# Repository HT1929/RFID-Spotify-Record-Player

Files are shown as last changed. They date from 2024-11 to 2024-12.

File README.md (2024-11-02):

# RFID-Spotify-Record-Player
Instead of vinyl records, RFID chips embedded in custom-made mini-records will trigger specific Spotify songs via a Raspberry Pi. The system mimics the action of placing a record on a turntable, offering both a visual spinning effect and the vast music library of Spotify.

# Project Overview
The RFID Spotify Record Player allows users to:
- Play, pause, skip and control volume for Spotify tracks.
- Select songs or playlists through a physical interface using the RFID sensor.
- Output audio through a built-in speaker system.
- Watch a disk spin as if it were playing a vinyl record, adding to the aesthetic of a traditional record player.

# Features
**User Interface:** Physical controls for playback and navigation.

**Controller:** Manages user inputs and communicates with Spotify.

**Network Module:** Connects to Wi-Fi to access the Spotify API.

**Spinning Disk:** A motorized disk spins to mimic the look of a record on a turntable.

**Spotify Integration:** Streams music directly from Spotify using the Spotify API.

**Audio Output:** Plays audio through connected speakers.

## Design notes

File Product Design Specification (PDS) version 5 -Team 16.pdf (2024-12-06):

### Practicum Product Design Specification (PDS)

Team 16

RFID Spotify Record Player

Date: 12/5/2024

Version 5

Lam Vo, Hiep Thieu
Natalie Kashoro, Daisy Perez-Ruiz

Executive Summary with Concept of Operations:
The RFID Spotify Record Player bridges the nostalgic experience of using a record player with the convenience of digital music streaming. Instead of vinyl records, RFID chips embedded in custom made mini-records will trigger specific Spotify songs via a Raspberry Pi. The system mimics the action of placing a record on a turntable, offering both a visual spinning effect and the vast music library of Spotify.

How it works:

- The user places an RFID-embedded "record" on the player.
- The RFID reader detects the tag.
- The Raspberry Pi processes this input, sends a command to Spotify to play a specific song, and simultaneously activates a DC motor to spin the mini-record for a visual effect.

Users:
Music enthusiasts who enjoy a blend of old-school vinyl aesthetics with modern music streaming.

Market Analysis:

- Target Users: Retro tech enthusiasts and individuals who appreciate unique user interfaces for their music experience.
- Competition: Competitors may include similar DIY projects combining Raspberry Pi, Spotify, and RFID. However, most of these don’t focus on the retro look and feel of a record player combined with Spotify.
- Unique Selling Point (USP): The product stands out for offering a visually satisfying, tactile experience with the practical convenience of Spotify's music library.
- Price Estimation: The expected price for parts and assembly would be around $100-$150, keeping it affordable compared to high-end custom audio systems, but competitive for a niche product.

Requirements:

- Must accurately read RFID tags within 1-2 seconds.
- Must connect to Spotify via a Wi-Fi or Ethernet connection.
- Must trigger a corresponding song and/or playlist based on the RFID chip.
- Must offer a smooth, lag-free music playing experience.
- Must not overheat during extended use.
- Should include a visual spinning effect of the mini-record.
- Should include an LCD displaying the song playing.
- Should be portable and powered (ex. standard AC adapter / rechargeable battery)
- Should have action buttons/RFID tags to control pause, play, skip, and reverse.
- Should be easy to set up with minimal configuration needed by the user.
- Should have a "shuffle" mode for random song playback.
- Should include a time display or countdown of the song playing.
- Should have adjustable volume control via buttons or a rotary knob.
- Should include support for multiple user profiles, allowing different users to have personalized playlists or settings.
- Should have a low-power mode to conserve battery when not in active use.
- Should offer a sleep timer that gradually lowers volume and shuts off after a set time.
- Should have a “favorite” button that lets users save the current track to a playlist.
- Should provide an adjustable motor speed to create different visual effects for the spinning disc.
- Should provide a visual notification for low signal strength if the Wi-Fi connection is weak.
- Should include a mute button to instantly stop sound output without turning off the device.
- Should provide an option to adjust the brightness of the LCD display.
- Should offer a feature to create playlists from RFID tags based on user preferences.

System Architecture:

- Level 0 Block Diagram:

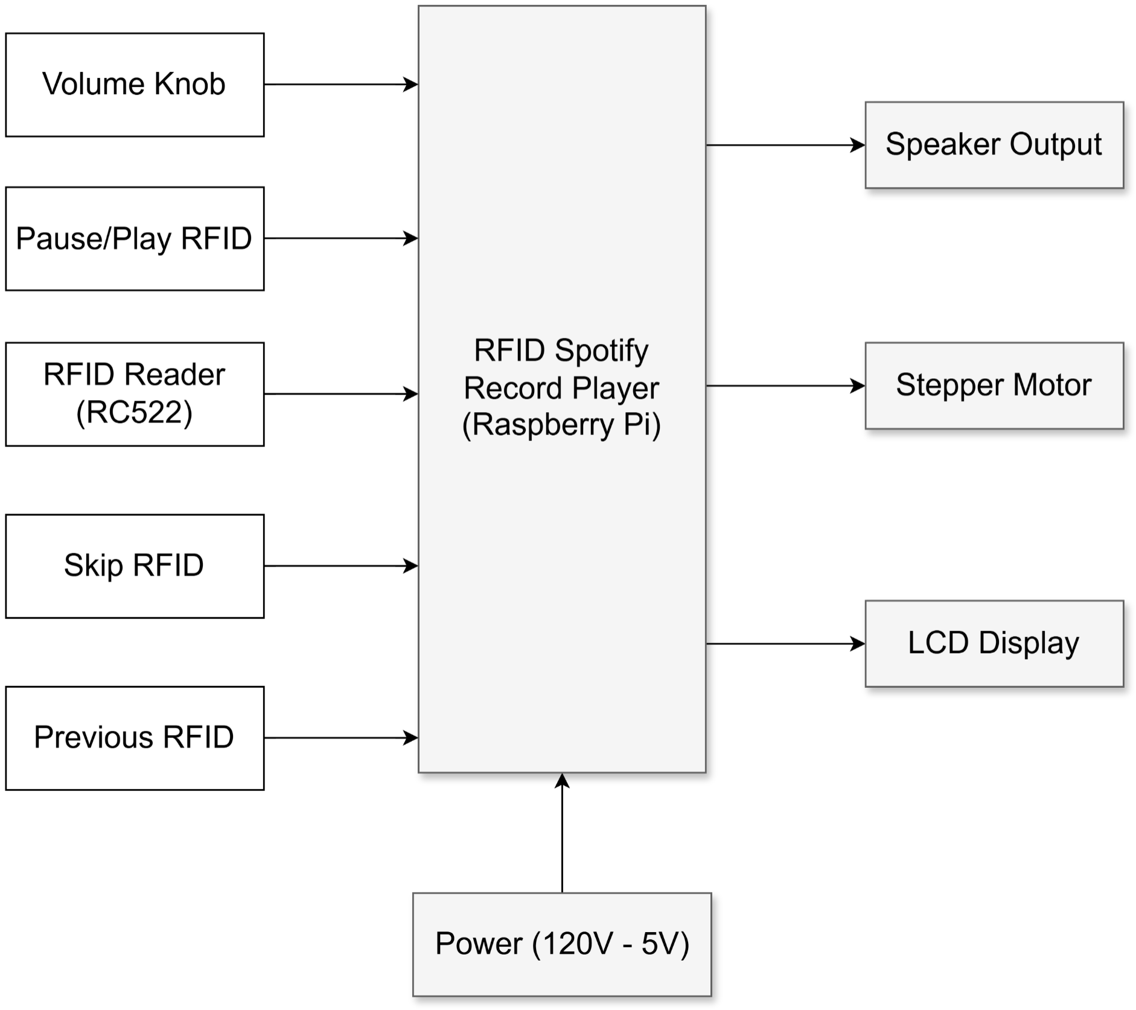
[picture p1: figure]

Module | RFID Spotify Record Player (Raspberry Pi)

Input | Volume knob Pause/play button RFID reader(RC522) Skip button Previous button Power(wall outlet 120V to input 5V)
Output | Speaker output Stepper motor LCD display
Functionality | Receive signal from RFID tag and process it to link with Spotify playlist and output the playlist.
- Level 1 Block Diagram:

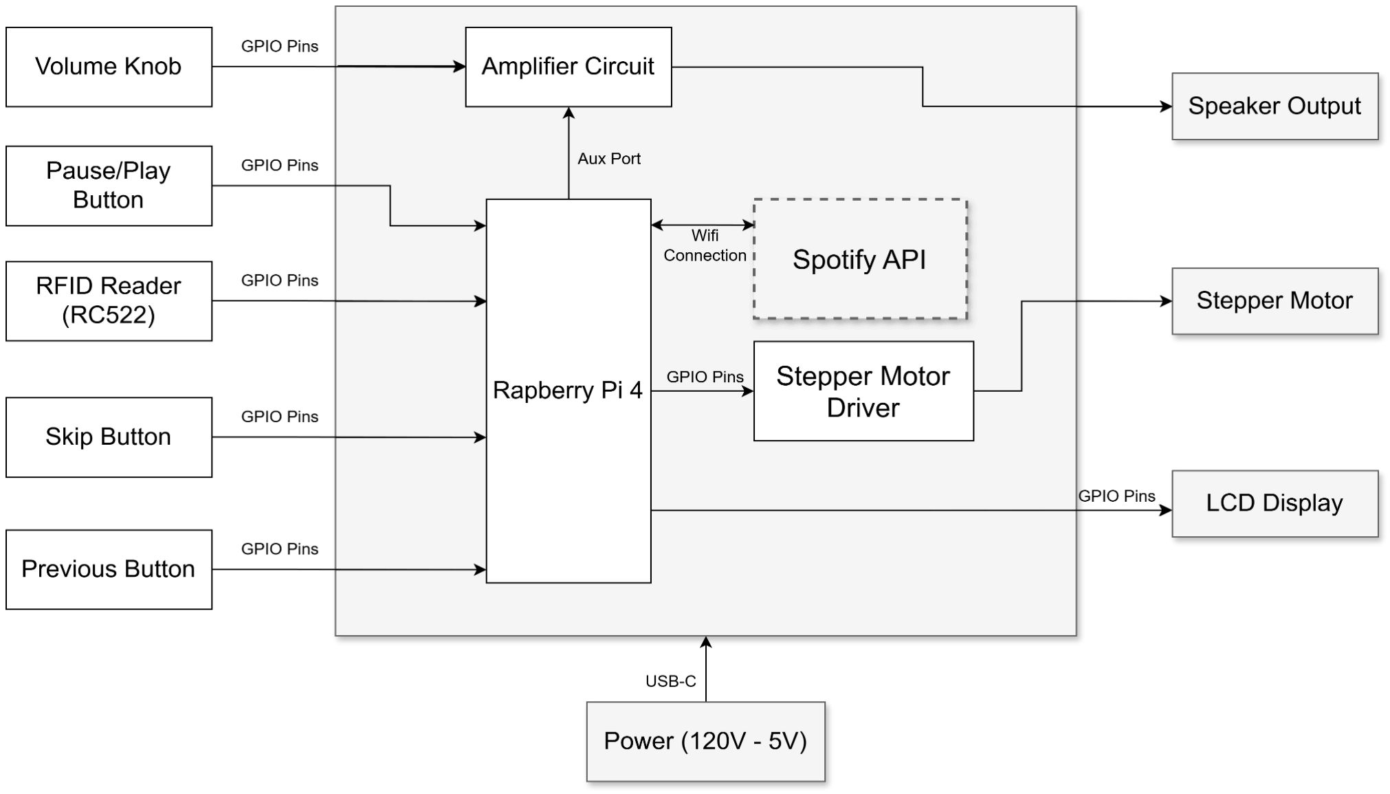
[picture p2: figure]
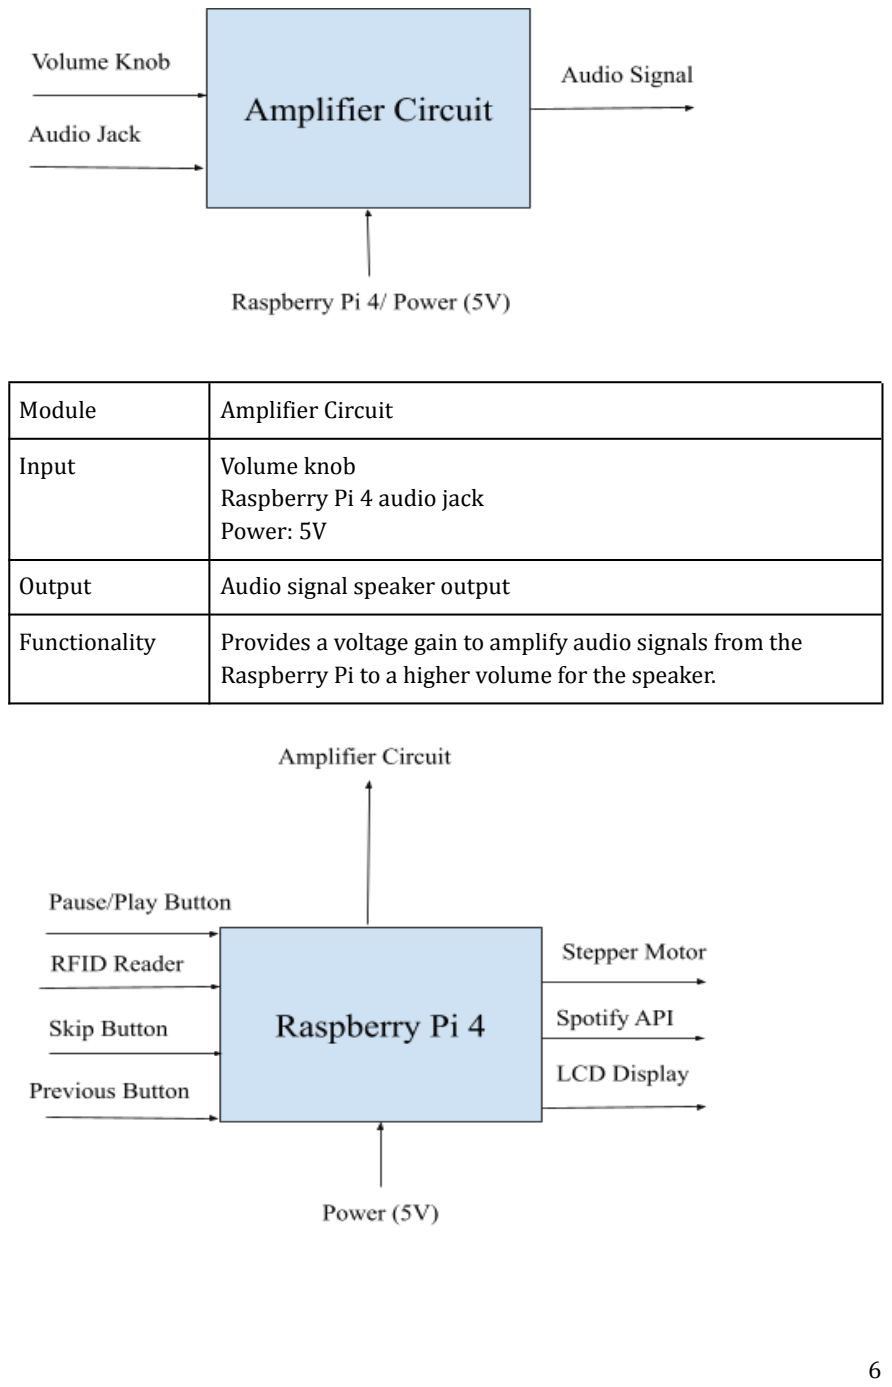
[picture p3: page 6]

Module | Amplifier Circuit
Input | Volume knob Raspberry Pi 4 audio jack Power: 5V
Output | Audio signal speaker output
Functionality | Provides a voltage gain to amplify audio signals from the Raspberry Pi to a higher volume for the speaker.

Module | Raspberry Pi 4
Input | Pause/play button RFID reader Skip button Previous button Power: 5V
Output | Stepper motor Spotify API LCD display
Functionality | Reads RFID tags, communicates with Spotify API to play corresponding songs, controls playback functions, and sends data to the LCD Display and stepper motor.

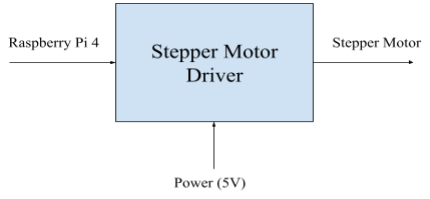
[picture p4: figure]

Module | Stepper Motor Driver
Input | Raspberry Pi 4 Power: 5V
Output | Stepper motor
Functionality | Controls the rate of rotation of the stepper motor to spin the mini-record player, simulating a traditional record player effect.

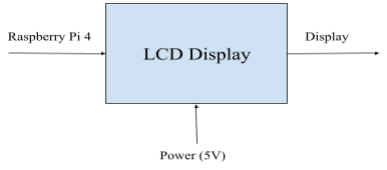
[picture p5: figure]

Module | LCD Display
Input | Raspberry Pi 4 Power: 5V
Output | LCD display
Functionality | Display the song title, playback control performed, or errors in playing a song.

Design Specification:

- Sensor: RFID reader (RC522 module).
- Processor: Raspberry Pi 4 (handles RFID reading, Spotify API interaction, and motor control).
- Actuator: Small DC motor to spin the mini-record.
- Display: LCD screen to show song details, playback controls, and status notifications.
- Power Supply: 5V, 2.5A power supply for Raspberry Pi; 5V motor driver (same power connection).
- Software: Python scripts for RFID reading and interfacing with Spotify's API; Motor control, and LCD Management via GPIO.
- Mechanical Design: Mini-record platter driven by a DC motor, audio jack-connected speaker, and integrated LCD for feedback.
- Firmware/Development Environment: Raspberry Pi OS, Python, Spotify API, and necessary libraries for LCD control.

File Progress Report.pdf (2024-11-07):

Team 16
Professor Greenberg
11/7/2024

Status Report: RFID Spotify Record Player

Project Overview:
The RFID Spotify Record Player aims to combine the nostalgic experience of a traditional record player with the convenience of digital streaming. Utilizing RFID chips embedded within custom miniature records, the device initiates playback of specific songs on Spotify through a Raspberry Pi. A DC motor enhances the experience by creating a rotating visual effect, mimicking the traditional record-playing ambiance.

Current Status:
The project is progressing on schedule, and a working prototype without an LCD screen has been completed. Major achievements include:
- Concept and Design Completed: The overall design, including the Level 0 and Level 1 block diagrams, has been finalized. These diagrams map out the system’s major components and their interactions, providing a clear visual foundation for implementation.
- Component Selection: The Raspberry Pi, RC522 RFID reader module, and DC motor have been selected as primary hardware components. Initial tests indicate compatibility with the project’s requirements.
- Software Integration Completed: The RFID reader has been successfully integrated with the Spotify API, enabling song playback based on the RFID tag input.

Project Pictures:

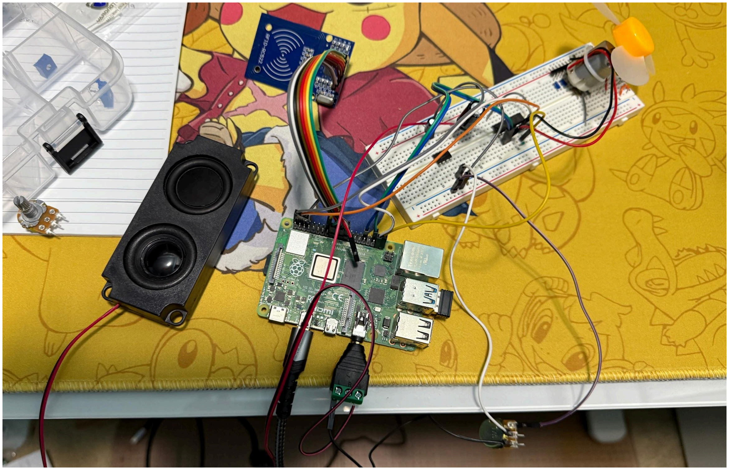
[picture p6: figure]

Video link:
https://drive.google.com/file/d/1K7AMLiBzfWugOn-8HSeIKXvq5kMZzPSX/view?usp=drive_l ink (https://drive.google.com/file/d/1K7AMLiBzfWugOn-8HSeIKXvq5kMZzPSX/view?usp=drive_link)

Next Steps:
1. Acquire and integrate an LCD screen for displaying the song title and playback status.
2. Design and test an amplifier circuit to enhance audio quality and volume.
3. 3D printing custom components for the player casing and mini-record holders will complete the visual design.
4. Conduct full-system testing to ensure reliability, smooth operation, and user experience.

Challenges:
- Speaker Amplification: The audio output from the Raspberry Pi lacks sufficient power to drive the speaker at a higher volume, requiring an amplifier solution.
- 3D Printing Fit and Quality: Ensuring that custom 3D-printed parts fit well with the prototype and align with the visual design.

Conclusion:
While the project is progressing well, with essential components and preliminary software development already established, it is important to continue staying on schedule due to the time limitations. We will be facing some challenges within the coming weeks, but will remain focused on integration and testing to advance toward a fully functional prototype.

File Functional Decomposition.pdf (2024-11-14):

Team 16
Professor Greenberg
ECE 424
11/14/2024

Functional Decomposition

Level 0 Block Diagram:

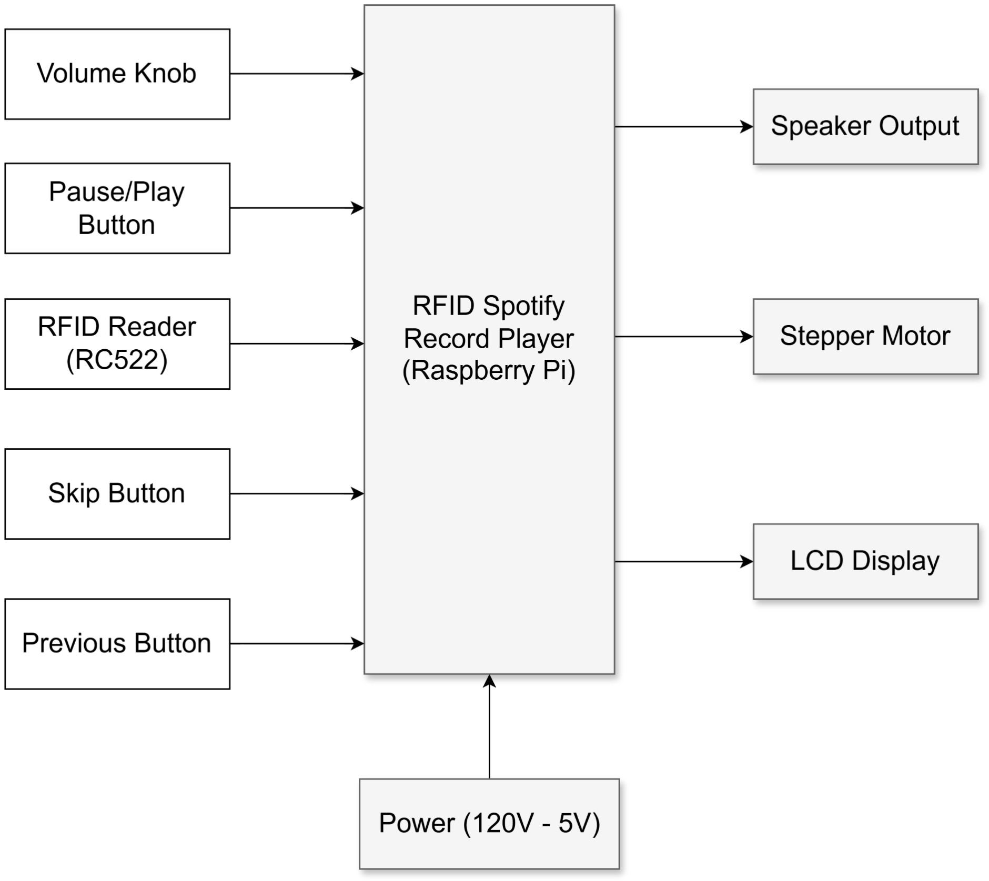
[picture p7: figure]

Module | RFID Spotify Record Player (Raspberry Pi)
Input | Volume knob Pause/play button RFID reader(RC522) Skip button Previous button Power(wall outlet 120V to input 5V)
Output | Speaker output Stepper motor LCD display
Functionality | Receive signal from RFID tag and process it to link with Spotify playlist and output the playlist.

Level 1 Block Diagram:

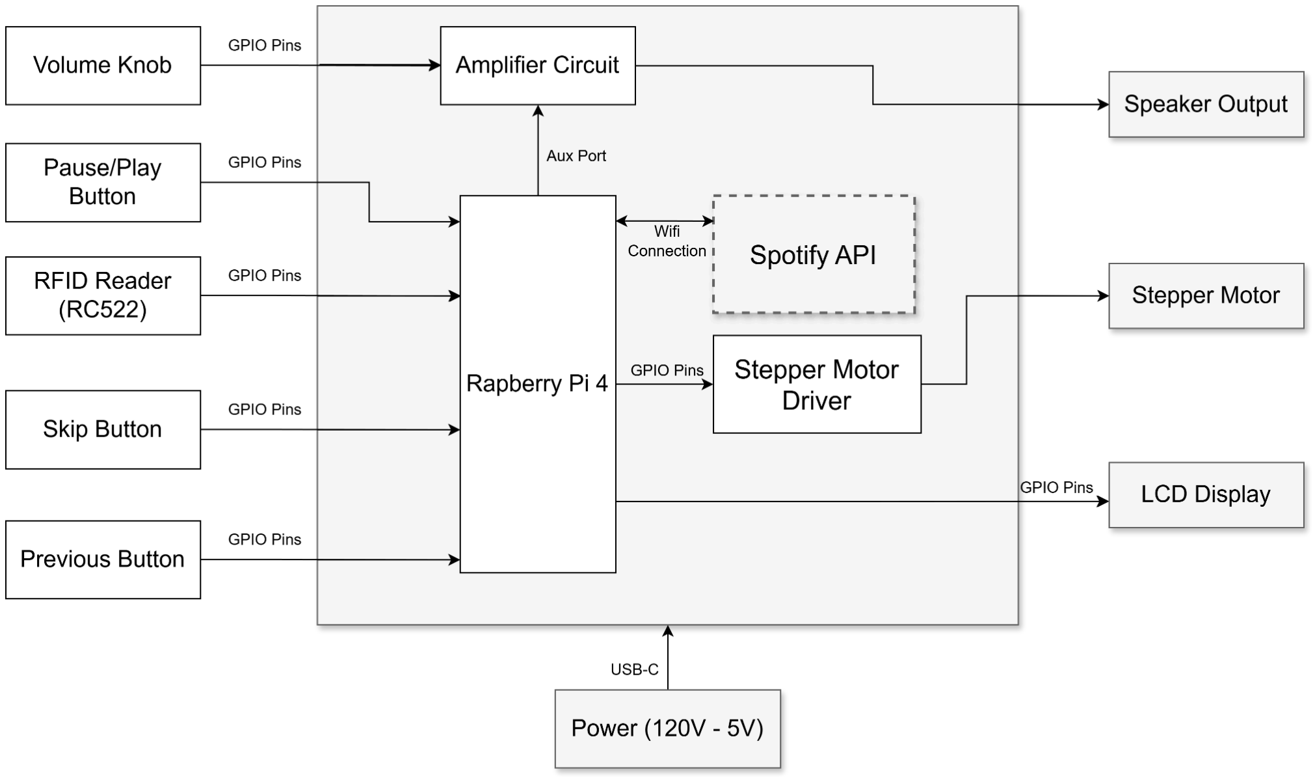
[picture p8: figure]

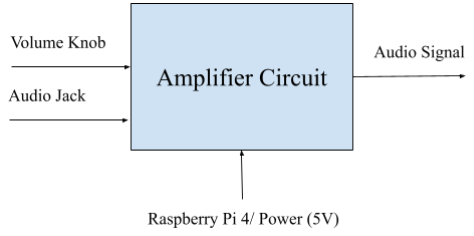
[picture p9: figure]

Module | Amplifier Circuit
Input | Volume knob Raspberry Pi 4 audio jack Power: 5V
Output | Audio signal speaker output
Functionality | Provides a voltage gain to amplify audio signals from the Raspberry Pi to a higher volume for the speaker.

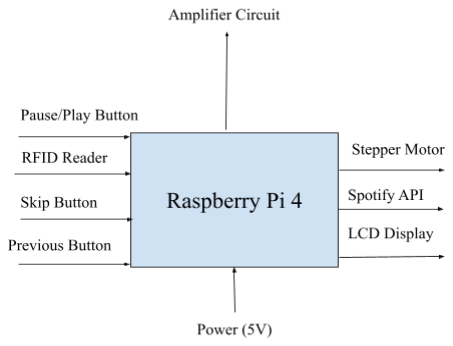
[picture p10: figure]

Module | Raspberry Pi
Input | Pause/play button RFID reader Skip button Previous button Power: 5V
Output | Stepper motor Spotify API LCD display
Functionality | Reads RFID tags, communicates with Spotify API to play corresponding songs, controls playback functions, and sends data to the LCD Display and stepper motor.

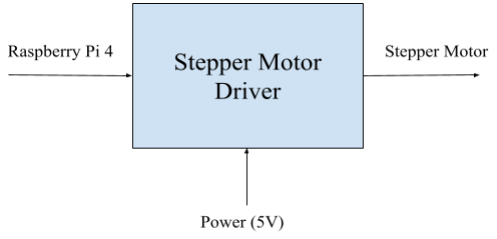
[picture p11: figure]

Module | Stepper Motor Driver
Input | Raspberry Pi 4 Power: 5V
Output | Stepper motor
Functionality | Controls the rate of rotation of the stepper motor to spin the mini-record player, simulating a traditional record player effect.

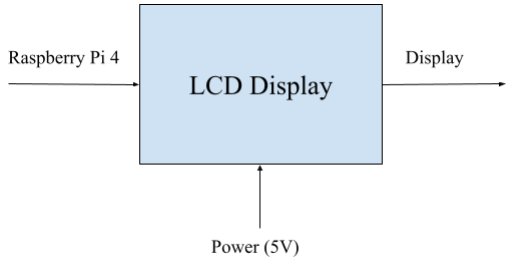
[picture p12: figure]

Module | LCD Display
Input | Raspberry Pi 4 Power: 5V
Output | LCD display
Functionality | Display the song title, playback control performed, or errors in playing a song.

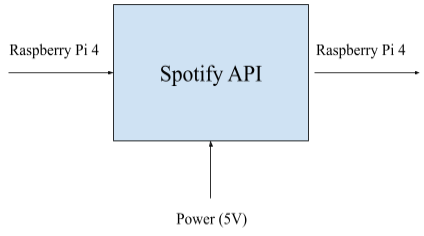
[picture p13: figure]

Module | Spotify API
Input | Pause/play command RFID reader Skip command Previous command Power: 5V
Output | Music playback
Functionality | Connects with Spotify to stream the selected song based on RFID input and provides playback control.

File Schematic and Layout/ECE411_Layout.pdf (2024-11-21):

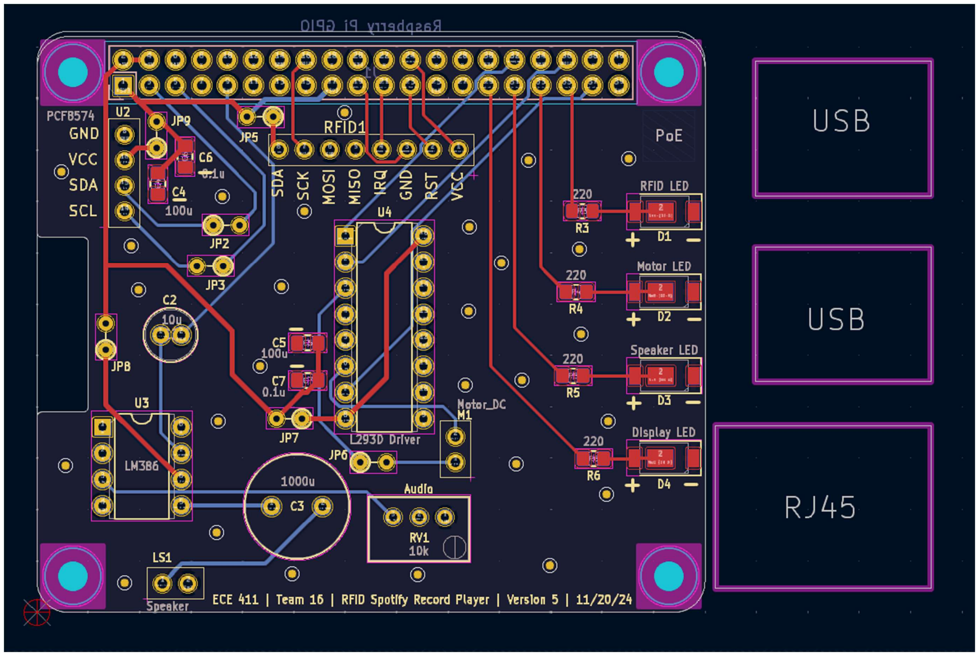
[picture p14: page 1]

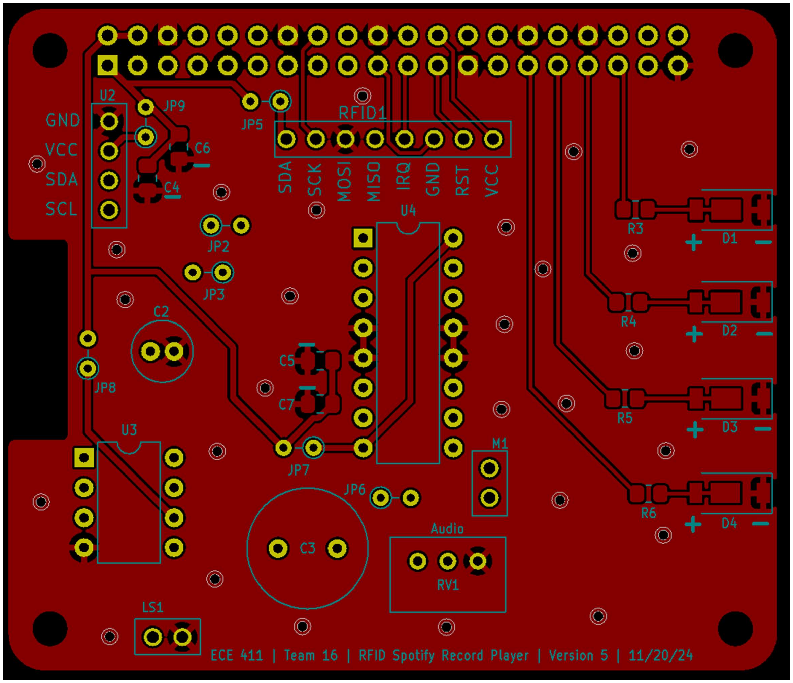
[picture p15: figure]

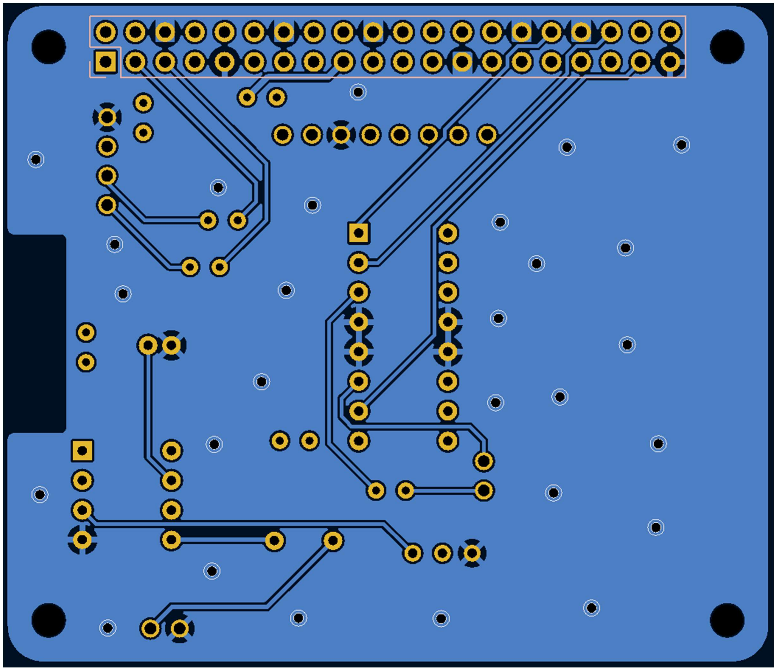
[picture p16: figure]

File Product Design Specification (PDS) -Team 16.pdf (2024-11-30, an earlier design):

### Practicum Product Design Specification (PDS)

Team 16

RFID Spotify Record Player

Date: 11/19/2024

Version 3

Lam Vo, Hiep Thieu
Natalie Kashoro, Daisy Perez-Ruiz

Executive Summary with Concept of Operations:
The RFID Spotify Record Player bridges the nostalgic experience of using a record player with the convenience of digital music streaming. Instead of vinyl records, RFID chips embedded in custom made mini-records will trigger specific Spotify songs via a Raspberry Pi. The system mimics the action of placing a record on a turntable, offering both a visual spinning effect and the vast music library of Spotify.

How it works:

- The user places an RFID-embedded "record" on the player.
- The RFID reader detects the tag.
- The Raspberry Pi processes this input, sends a command to Spotify to play a specific song, and simultaneously activates a DC motor to spin the mini-record for a visual effect.

Users:
Music enthusiasts who enjoy a blend of old-school vinyl aesthetics with modern music streaming.

Market Analysis:

- Target Users: Retro tech enthusiasts and individuals who appreciate unique user interfaces for their music experience.
- Competition: Competitors may include similar DIY projects combining Raspberry Pi, Spotify, and RFID. However, most of these don’t focus on the retro look and feel of a record player combined with Spotify.
- Unique Selling Point (USP): The product stands out for offering a visually satisfying, tactile experience with the practical convenience of Spotify's music library.
- Price Estimation: The expected price for parts and assembly would be around $100-$150, keeping it affordable compared to high-end custom audio systems, but competitive for a niche product.

Requirements:

- Must accurately read RFID tags within 1-2 seconds.
- Must connect to Spotify via a Wi-Fi or Ethernet connection.
- Must trigger a corresponding song and/or playlist based on the RFID chip.
- Must offer a smooth, lag-free music playing experience.
- Must not overheat during extended use.
- Should include a visual spinning effect of the mini-record.
- Should include an LCD displaying the song playing.
- Should be portable and powered (ex. standard AC adapter / rechargeable battery)
- Should have action buttons/RFID tags to control pause, play, skip, and reverse.
- Should be easy to set up with minimal configuration needed by the user.
- Should have a "shuffle" mode for random song playback.
- Should include a time display or countdown of the song playing.
- Should have adjustable volume control via buttons or a rotary knob.
- Should include support for multiple user profiles, allowing different users to have personalized playlists or settings.
- Should have a low-power mode to conserve battery when not in active use.
- Should offer a sleep timer that gradually lowers volume and shuts off after a set time.
- Should have a “favorite” button that lets users save the current track to a playlist.
- Should provide an adjustable motor speed to create different visual effects for the spinning disc.
- Should provide a visual notification for low signal strength if the Wi-Fi connection is weak.
- Should include a mute button to instantly stop sound output without turning off the device.
- Should provide an option to adjust the brightness of the LCD display.
- Should offer a feature to create playlists from RFID tags based on user preferences.

System Architecture:

- Level 0 Block Diagram:

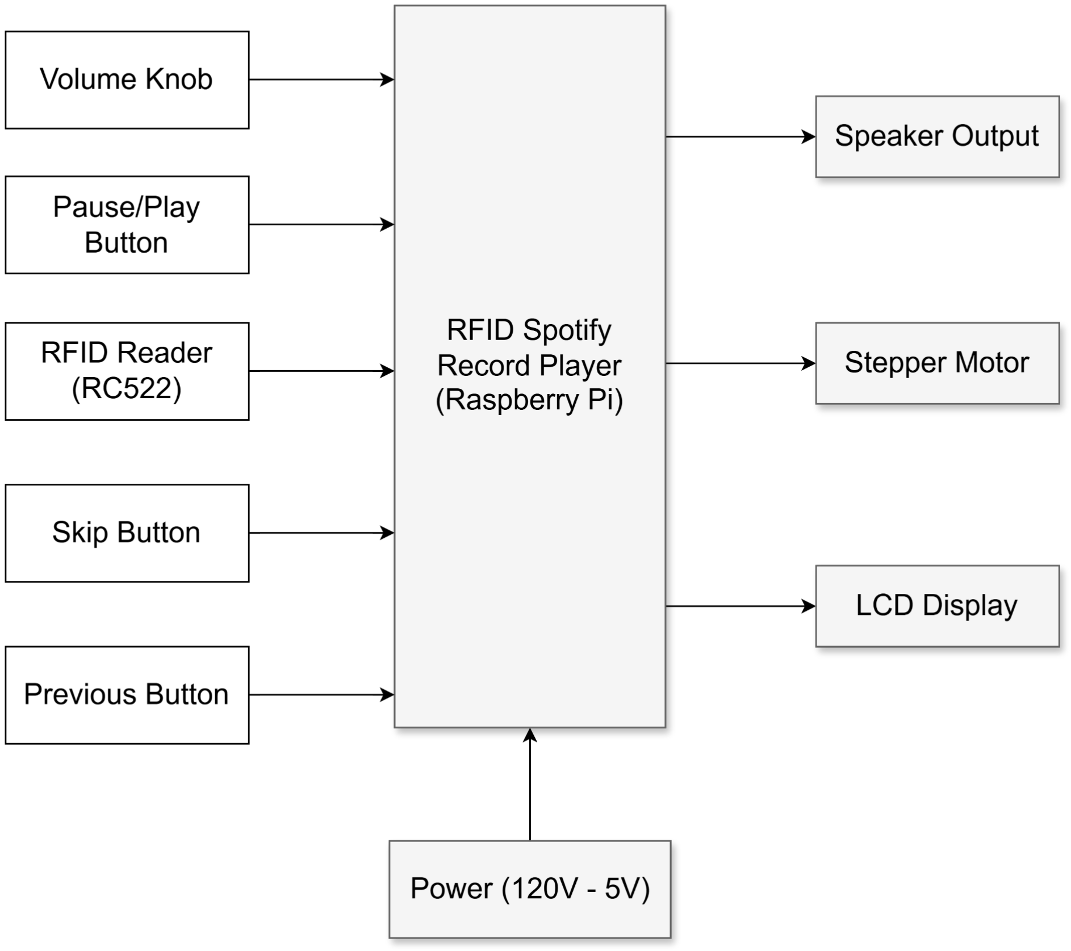
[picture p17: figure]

Module | RFID Spotify Record Player (Raspberry Pi)
Input | Volume knob Pause/play button RFID reader(RC522) Skip button Previous button Power(wall outlet 120V to input 5V)
Output | Speaker output Stepper motor LCD display
Functionality | Receive signal from RFID tag and process it to link with Spotify playlist and output the playlist.
- Level 1 Block Diagram:

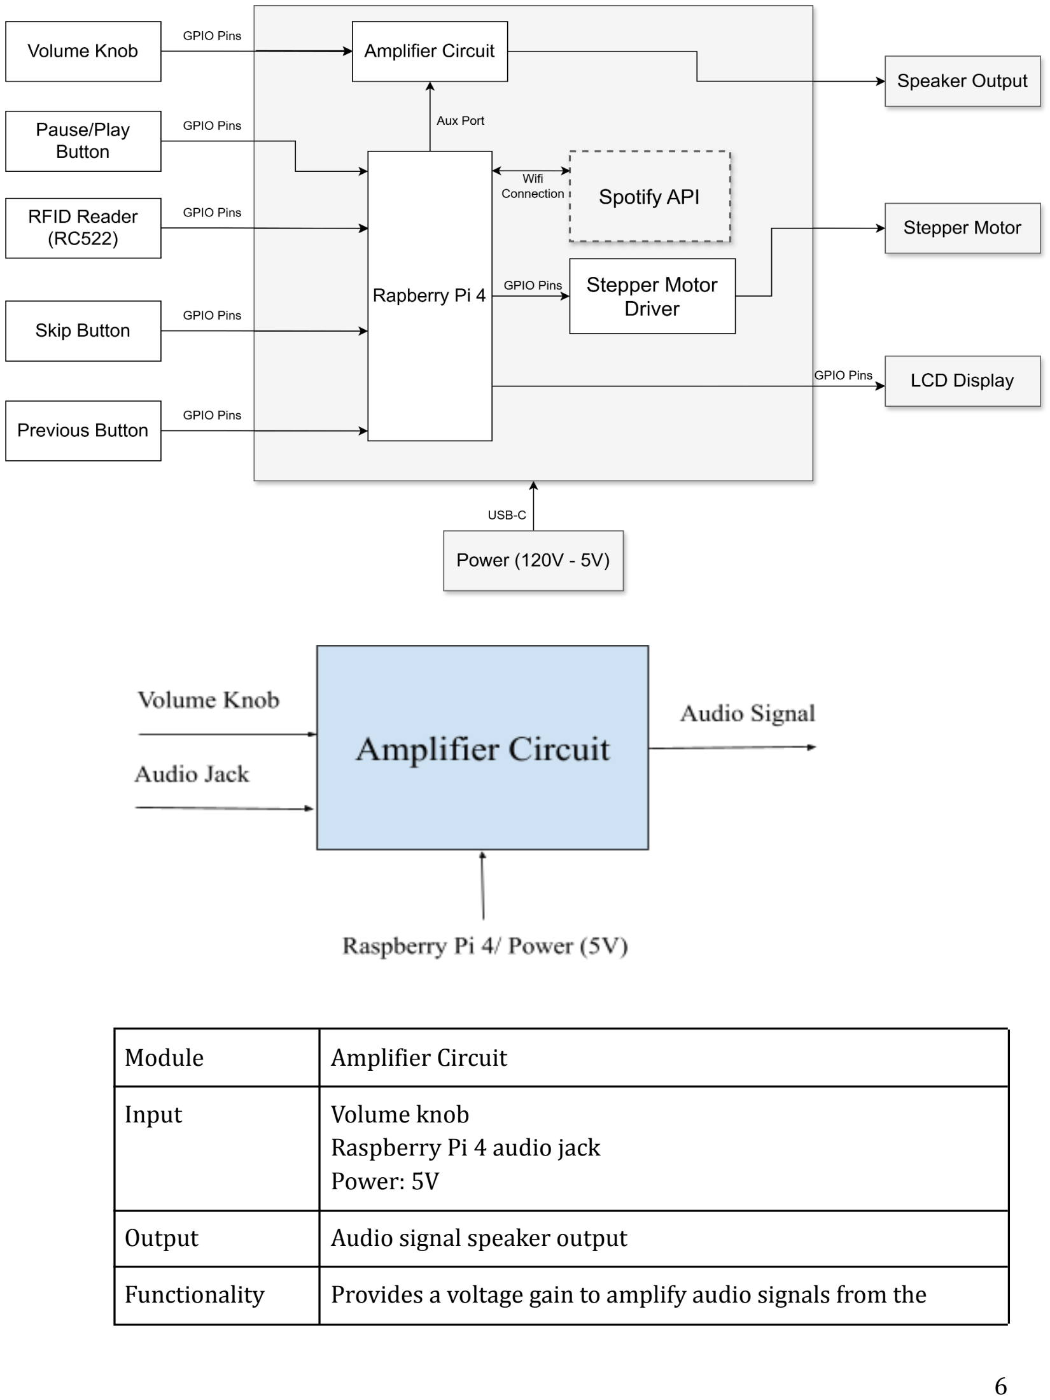
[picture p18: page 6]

Module | Amplifier Circuit
Input | Volume knob Raspberry Pi 4 audio jack Power: 5V
Output | Audio signal speaker output
Functionality | Provides a voltage gain to amplify audio signals from the

Raspberry Pi to a higher volume for the speaker.

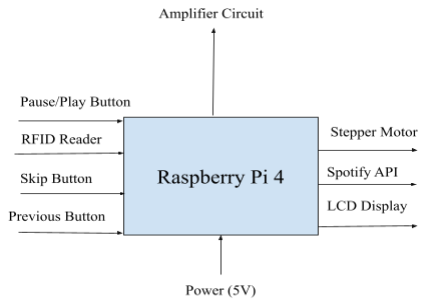
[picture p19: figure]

Module | Raspberry Pi 4
Input | Pause/play button RFID reader Skip button Previous button Power: 5V
Output | Stepper motor Spotify API LCD display
Functionality | Reads RFID tags, communicates with Spotify API to play corresponding songs, controls playback functions, and sends data to the LCD Display and stepper motor.

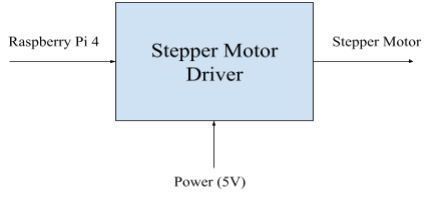
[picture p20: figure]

Module | Stepper Motor Driver
Input | Raspberry Pi 4 Power: 5V
Output | Stepper motor
Functionality | Controls the rate of rotation of the stepper motor to spin the mini-record player, simulating a traditional record player effect.

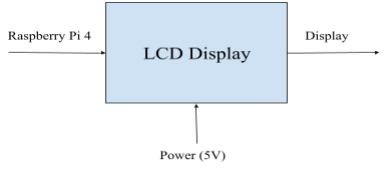
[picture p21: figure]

Module | LCD Display
Input | Raspberry Pi 4 Power: 5V
Output | LCD display
Functionality | Display the song title, playback control performed, or errors in playing a song.

Design Specification:

- Sensor: RFID reader (RC522 module).
- Processor: Raspberry Pi 4 (handles RFID reading, Spotify API interaction, and motor control).
- Actuator: Small DC motor to spin the mini-record.
- Power Supply: 5V, 2.5A power supply for Raspberry Pi; 5V motor driver (same power connection).
- Software: Python scripts for RFID reading and interfacing with Spotify's API; Motor control via GPIO.
- Mechanical Design: Mini-record platter driven by a DC motor and audio jack connected speaker.
- Firmware/Development Environment: Raspberry Pi OS, Python, Spotify API.

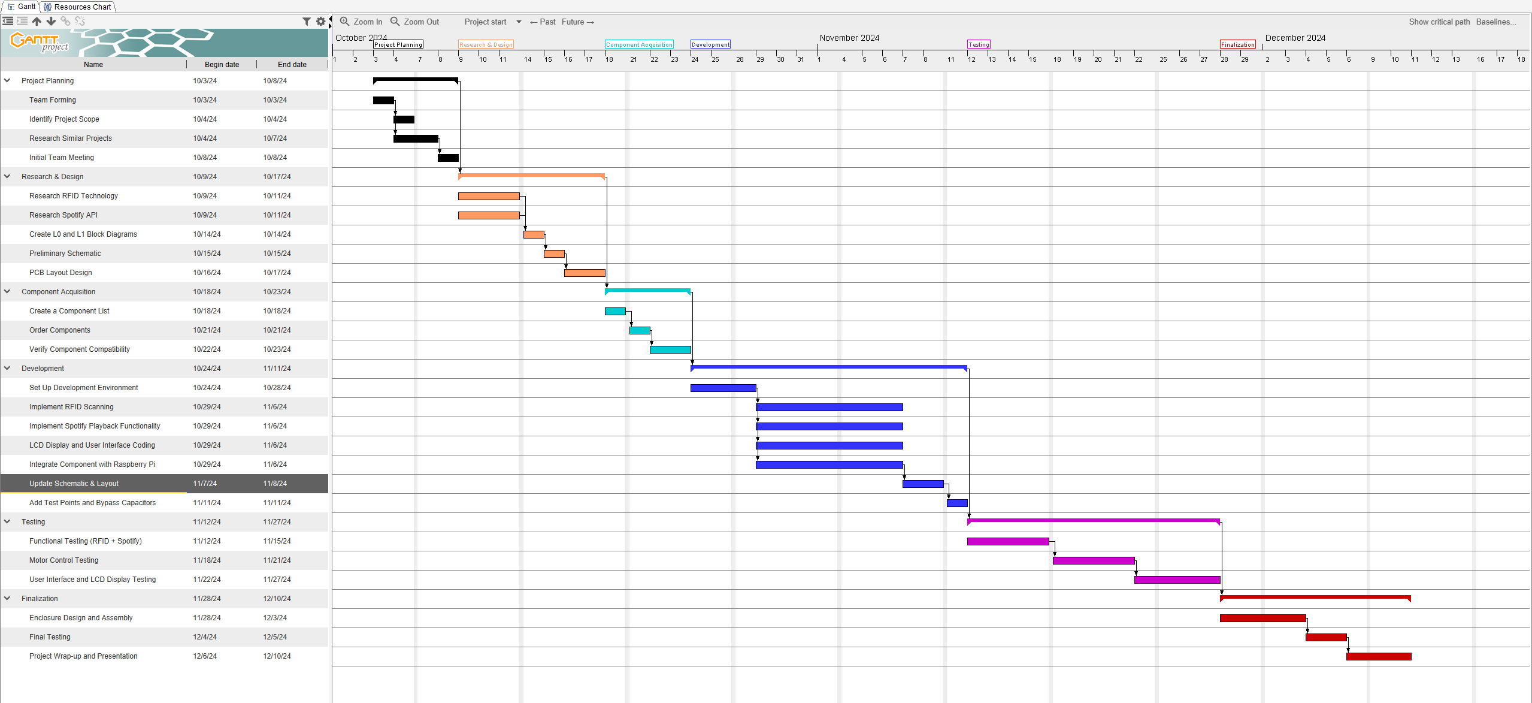
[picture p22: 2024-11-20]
Gantt_Chart/ECE 411 Gant Chart Updated.PNG

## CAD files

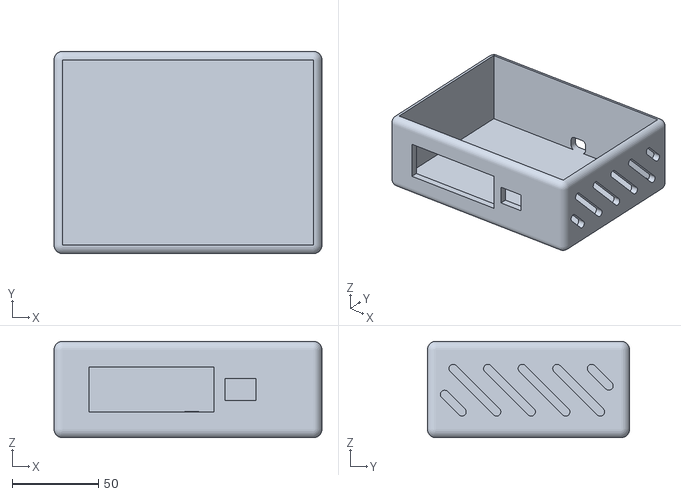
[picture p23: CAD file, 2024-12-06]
3D Design Model/box bottom v5.stl
155.0 x 117.0 x 55.8

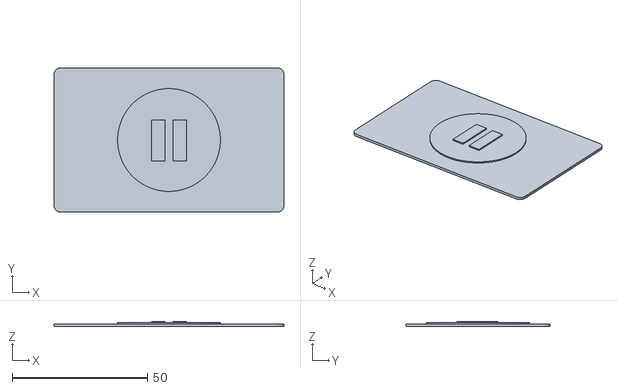
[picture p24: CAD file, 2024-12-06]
3D Design Model/pause v3.stl
85.0 x 53.3 x 2.00

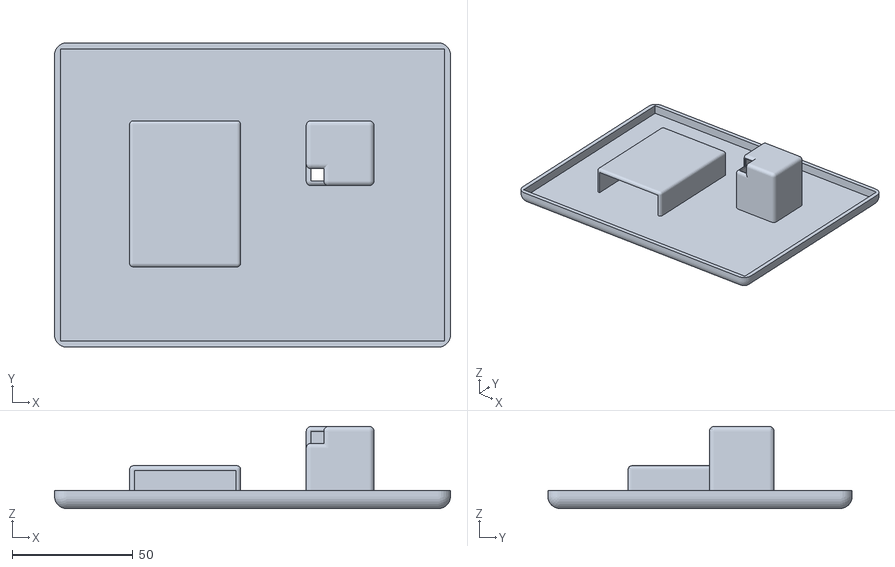
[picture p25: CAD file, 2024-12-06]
3D Design Model/bot top v4.stl
164.0 x 126.0 x 34.0

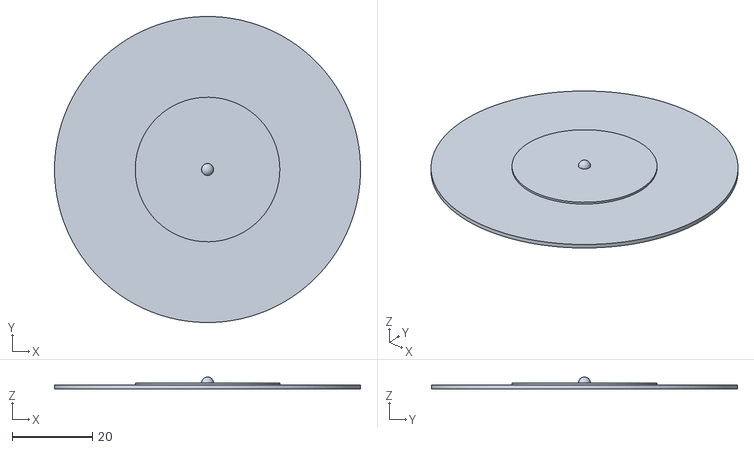
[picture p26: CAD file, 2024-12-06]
3D Design Model/disc v2.stl
76.2 x 76.2 x 3.00

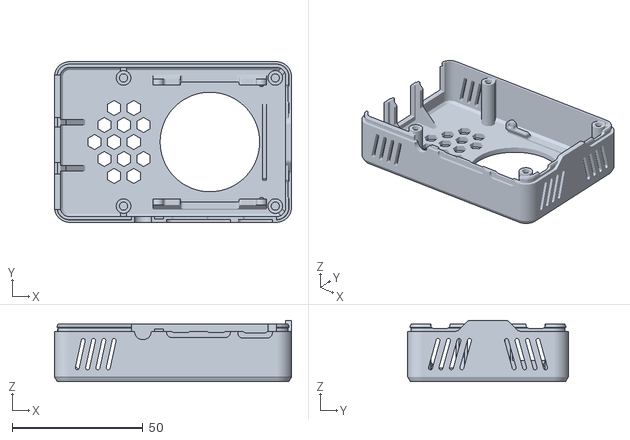
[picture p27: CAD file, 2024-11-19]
3D Design Model/3d_Top_rev1.stl
90.6 x 61.4 x 23.4

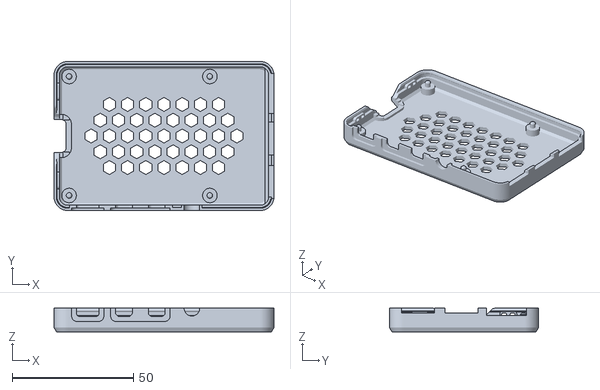
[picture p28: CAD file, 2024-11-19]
3D Design Model/3d_Bottom_rev1.stl
90.6 x 61.4 x 9.70

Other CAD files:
3D Design Model/play v2.stl
3D Design Model/skip v3.stl

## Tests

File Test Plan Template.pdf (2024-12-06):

Hiep Thieu, Lam Vo, Daisy Perez, Natalie Kashoro | 12/5/2024 | ECE 411

Test Author: Group 16
Test Case Name: | Music playing Path Test #1 | Test ID #: | MPP-01
Description: | Set up the RFID reader to identify tags linked to specific Spotify playlists and play the associated music through the connected speaker. | Type: | white box black box ________

Tester Information
| Name of Tester: | Hiep Thieu and Daisy Perez | Date: | Dec 4 2024
| HW/SW Version: | 1.0 | Time: | 2PM
| Setup: | Connect the Raspberry Pi to the audio system and an RFID scanner. Do not connect the jumpers for other subsystems.
S T E P | Action | Expected Result | P A S S | F A I L | N / A | Comments
1 | Have mobile device detect raspberry Pi | Spotify connects to raspotify | x | | | Raspotify is the raspberry pi name when searching on Spotify
2 | Begin Program | Volume should be low/muted, the output display screen should show “Scan RFID…” when program runs | x | | | Use a test code instead of the main, full code
3 | Scan song RFID | Spotify should load playlist on phone and begin playing | x
4 | Turn the volume down | Music coming from speaker should be louder | x
5 | Turn the volume up | Music coming from speaker should be quieter | x
6 | Scan music control RFIDs | Pause RFID - pause song, Play RFID - play song, skip RFID - skip song | x
7 | Register RFID | Add RFID id to database, display in the output screen completion or error message. | x | | | Should give error messages depending on the error. Common error we looked for was duplicate RFID trying to reregister.
| Overall test result: | | x
2024-12-5 | Page 1 of 3

Test Author: Group 16

Test Case Name: | RFID detection test | Test ID #: | DT-01
Description: | Verify the range in which the RFID tag can be from the sensor and still be read. | Type: | white box black box ________

Tester Information

| Name of Tester: | Natalie Kashoro and Lam Vo | Date: | Dec 3 2024
| HW/SW Version: | 1.0 | Time: | 8AM
| Setup: | Isolate the sensor from any other type of disruptions. We will be testing only perpendicular from the face of the RFID sensor, not diagonally or horizontally.
T E S T | Distance between RFID Scanner and the RFID Tag | Expected Output | P A S S | F A I L | N / A | Comments
1 | 0 cm | Command Prompt Message : “RFID Detected” | x
2 | 1 cm | Command Prompt Message : “RFID Detected” | x
3 | 2 cm | Command Prompt Message : “RFID Detected” | x
4 | 3 cm | Command Prompt Message : “RFID Detected” | x
5 | 4 cm | Command Prompt Message : “RFID Detected” | | x | | Might need to adjust the 3d printed case so the wall is not as thick
6 | 5 cm | Command Prompt Message : “RFID Detected” | | x | | Test again as a black box test to see if the sensor can detect the RFID tag through the box wall.

7 | 6 cm | Command Prompt Message : “RFID Detected” | | x
| Overall test result: | | x | | 4 cm should be an appropriate radius for the sensor because we want to avoid the possibility of scanning multiple RFIDS due to the larger radius

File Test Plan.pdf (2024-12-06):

Hiep Thieu, Lam Vo, Daisy Perez, Natalie Kashoro ECE 411
December 5, 2024

### Test Plan

Unit Test:
Power Supply
1. Check if the Raspberry Pi gets a steady 5V from the power adapter.
2. Verify that the 3.3V GPIO pin powers the RFID reader correctly.
3. Confirm the motor driver and LCD screen are powered from the 5V GPIO pin without overloading.
RFID Reader
4. Test if valid RFID tags embedded in mini-records are detected.
5. Check that unregistered tags are ignored.
6. Verify consistent detection when scanning multiple tags in a row.
Spinning Disk Motor
7. Confirm the motor spins when a control signal is sent from the Raspberry Pi GPIO pin.
8. Test the motor’s speed consistency while running.
9. Ensure the motor stops spinning when playback is paused.
Audio System
10. Verify sound output through the speakers is clear.
11. Test volume control to ensure it adjusts levels up and down as expected.
12. Check for distortion at maximum volume.
Physical Controls
13. Pressing the play button starts playback.
14. Pressing the pause button stops playback.
15. The skip button advances to the next track.
16. Volume buttons change the audio level accurately.
Spotify Integration
17. Verify the Spotify API triggers the correct song/playlist based on the RFID tag.
18. Ensure playback state (is_playing) updates correctly.
19. Check system response to Spotify errors like no internet connection.
LCD Screen
20. Ensure the LCD powers on and displays text correctly.
21. Check if it shows the current track and artist name.
22. Test scrolling for long song or artist names.

Verification Tests:
1. Mini-record triggers playback:
Placing a mini-record with an embedded RFID tag starts playback of the associated Spotify song or playlist.
2. Mini-record stops playback:
Removing the mini-record pauses Spotify playback and stops the spinning disk.
3. Play button starts playback:
Pressing the physical "Play" button resumes Spotify playback.
4. Pause button stops playback:
Pressing the "Pause" button pauses Spotify playback and stops the spinning disk.
5. Skip button advances track:
Pressing the "Skip" button skips to the next track in the playlist.
6. Volume up increases sound level:
Pressing the "Volume Up" button increases the volume through the built-in speakers.
7. Volume down decreases sound level:
Pressing the "Volume Down" button decreases the volume.
8. LCD updates current track:
When playback starts, the LCD displays the current track name and artist.
9. Scrolling for long text:
If the track name or artist exceeds 16 characters, the LCD scrolls the text smoothly.
10. Spinning disk starts with playback:
The motorized disk starts spinning when Spotify playback begins.
11. Spinning disk stops when paused:
The spinning disk halts when playback is paused or stopped.
12. Unregistered RFID tag has no effect:
Scanning an unregistered RFID tag does not start playback, display a track, or spin the disk.
13. Register new RFID tag to a playing song:
While a song is playing, register a new RFID tag to that song. After registering, scanning the tag should immediately trigger playback of the registered song.
14. Prevent re-registering a card:
If a registered RFID tag is scanned during a registration process, the system should display a message on the LCD (e.g., "Card already registered") and reject the re-registration.

Validation Tests:
Must Requirements:
1. Playback starts with mini-record: Placing a mini-record with an RFID tag starts Spotify playback and spins the disk.

2. Playback stops with mini-record removal: Removing the mini-record pauses Spotify playback and stops the spinning disk.
3. Correct song/playlist triggers:
The system plays the correct Spotify song or playlist associated with the RFID tag.
4. Handle unregistered tags:
Scanning an unregistered RFID tag displays "Tag not recognized" on the LCD and does not affect playback.
5. Track display on LCD:
The LCD shows the current Spotify track name and artist during playback.
6. Playback controls work:
- Play/pause buttons resume and pause playback.
- Skip button advances to the next track.
- Volume buttons adjust audio levels smoothly.
7. Spinning disk synchronizes with playback:
The motorized disk spins only during playback and stops immediately when playback halts.
8. Wi-Fi and Spotify connection:
The system connects to Wi-Fi and interacts with the Spotify API to retrieve and control playback.
9. Clear audio output:
The audio plays through the speakers without distortion.
Should Requirements
10. Scroll long text on LCD:
If the track name or artist name exceeds 16 characters, the LCD scrolls the text smoothly.
11. Volume sync with Spotify app:
Changes to volume on the system are reflected in the Spotify app and vice versa.
12. Prevent duplicate registration:
Attempting to register a tag already associated with a song displays "Card already registered" and rejects re-registration.
13. Delete RFID tag registration:
The system allows users to remove a tag's association with a song, and the tag is no longer recognized.
14. Error messages for network issues:
If the system loses Wi-Fi or Spotify access, the LCD shows an appropriate error message, like "No internet connection."
15. Recover from network loss:
The system reconnects to Wi-Fi and Spotify automatically after losing connection.

16. Power cycle recovery:
The system resumes functionality without losing data or requiring reconfiguration after a power cycle.
17. Unregistered tag feedback:
Scanning an unregistered RFID tag provides feedback like "Tag not recognized" on the LCD.
18. Error recovery:
The system gracefully handles unexpected conditions like invalid RFID scans or Spotify API rate limits without freezing.
May Requirements
19. Mute functionality:
The system provides a mute function to silence audio without stopping playback.
20. Manual disk stop:
A button allows the user to stop the spinning disk manually while playback continues.
21. Stereo output:
The system supports stereo audio output if connected to stereo speakers.
22. Multiple device playback compatibility:
The system functions correctly even if the Spotify account is in use on another device.

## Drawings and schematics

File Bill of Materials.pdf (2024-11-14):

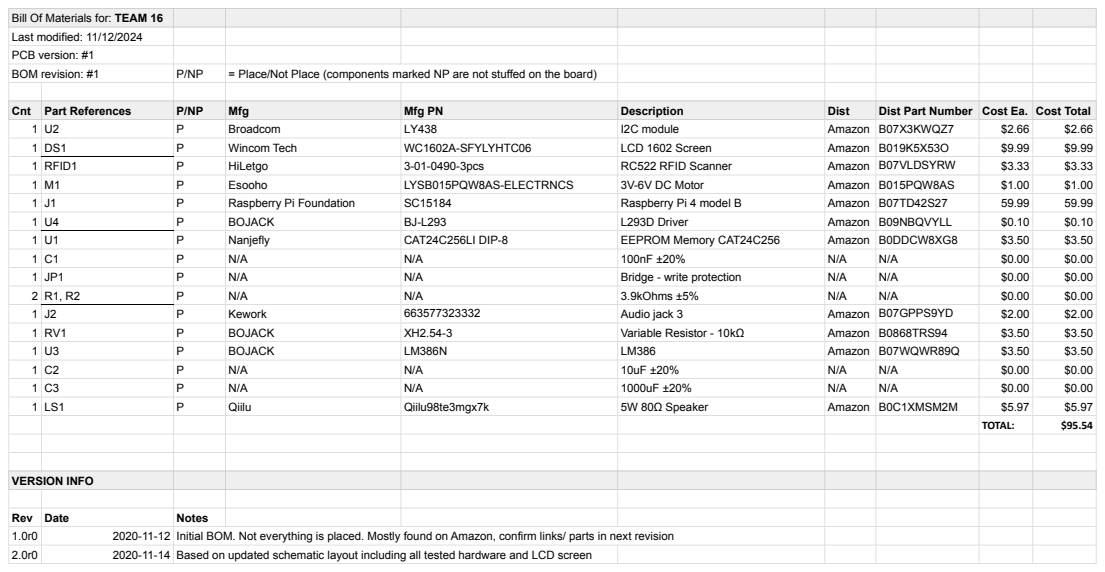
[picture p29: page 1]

Bill Of Materials for: TEAM 16
Last modified: 11/12/2024
PCB version: #1

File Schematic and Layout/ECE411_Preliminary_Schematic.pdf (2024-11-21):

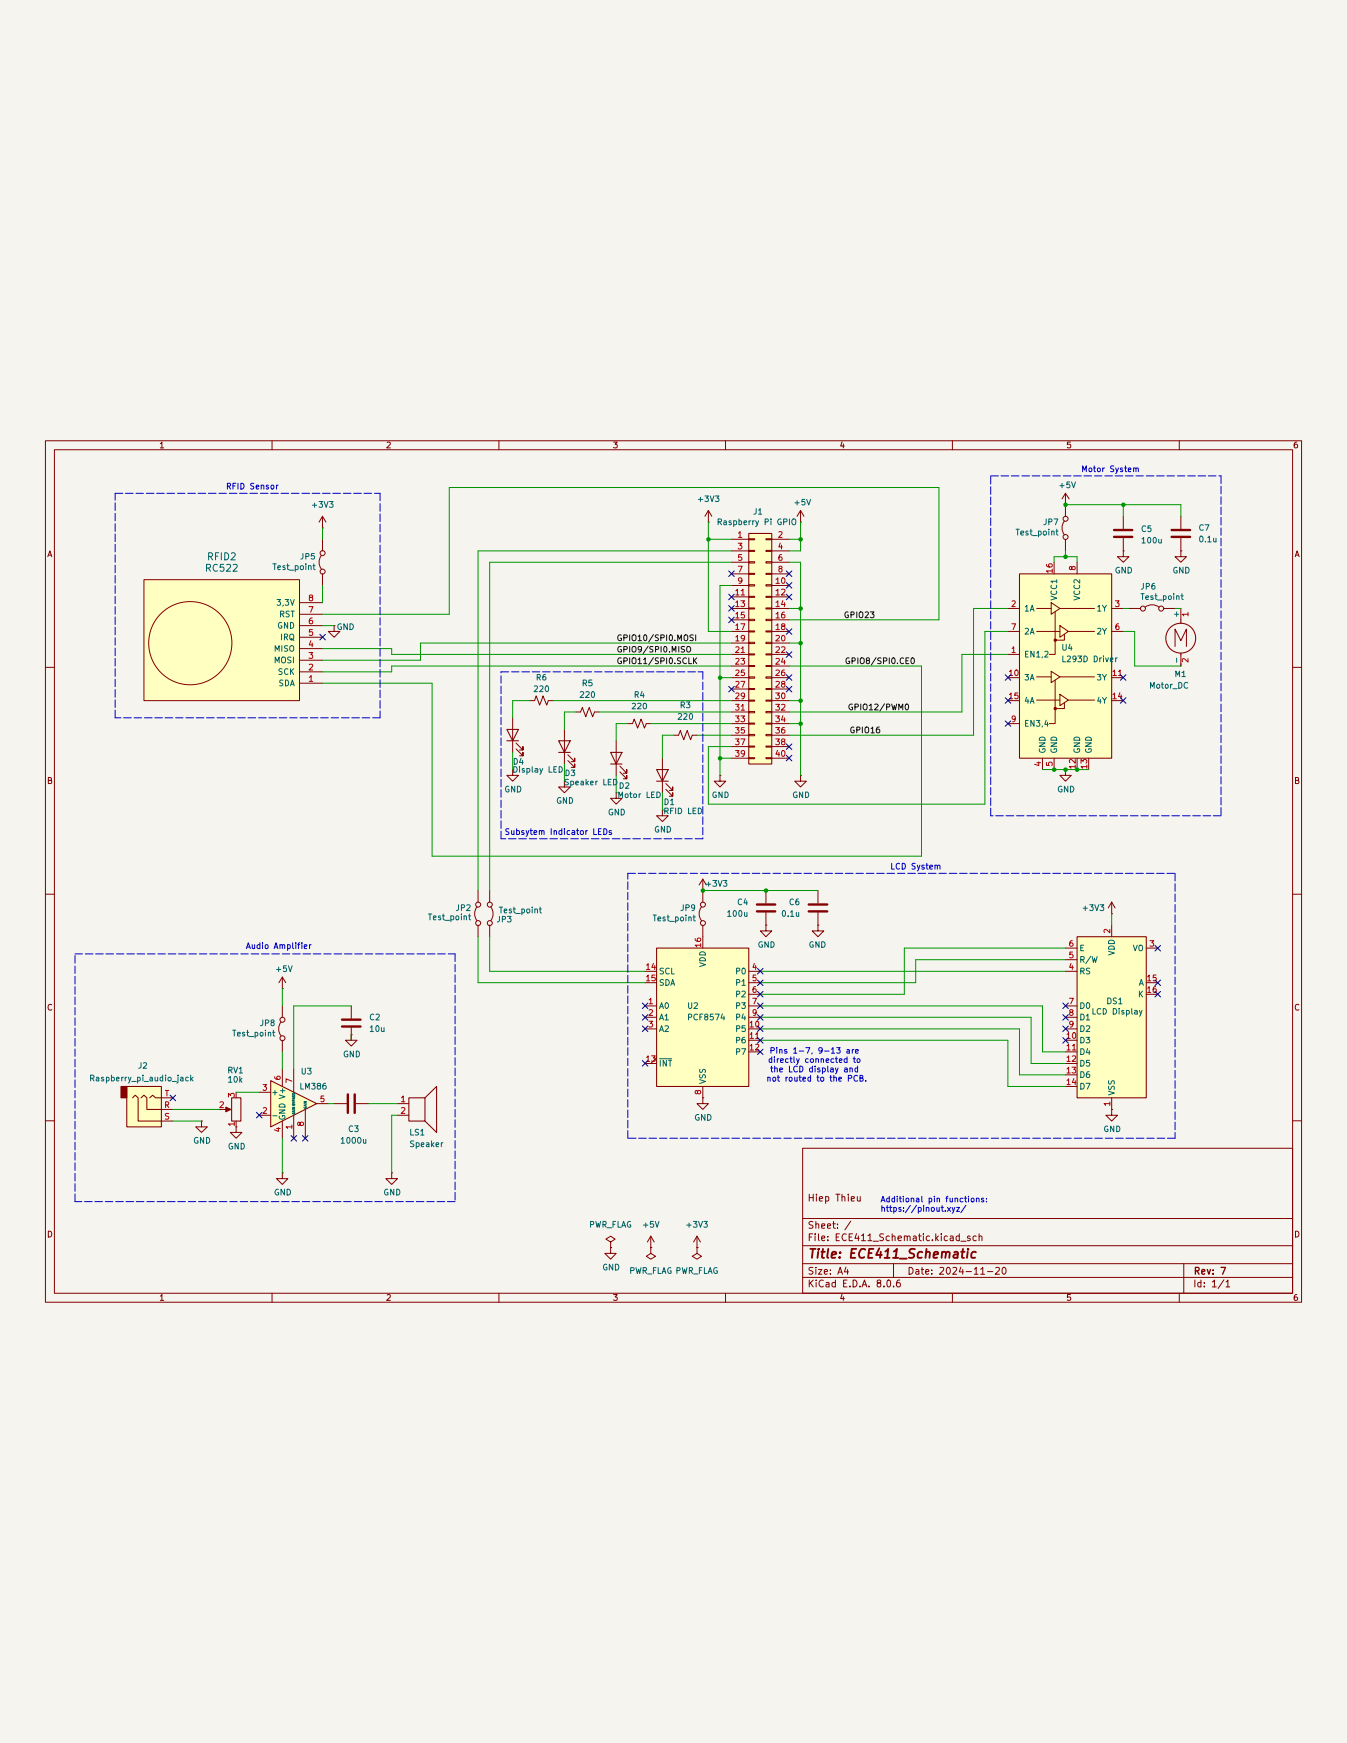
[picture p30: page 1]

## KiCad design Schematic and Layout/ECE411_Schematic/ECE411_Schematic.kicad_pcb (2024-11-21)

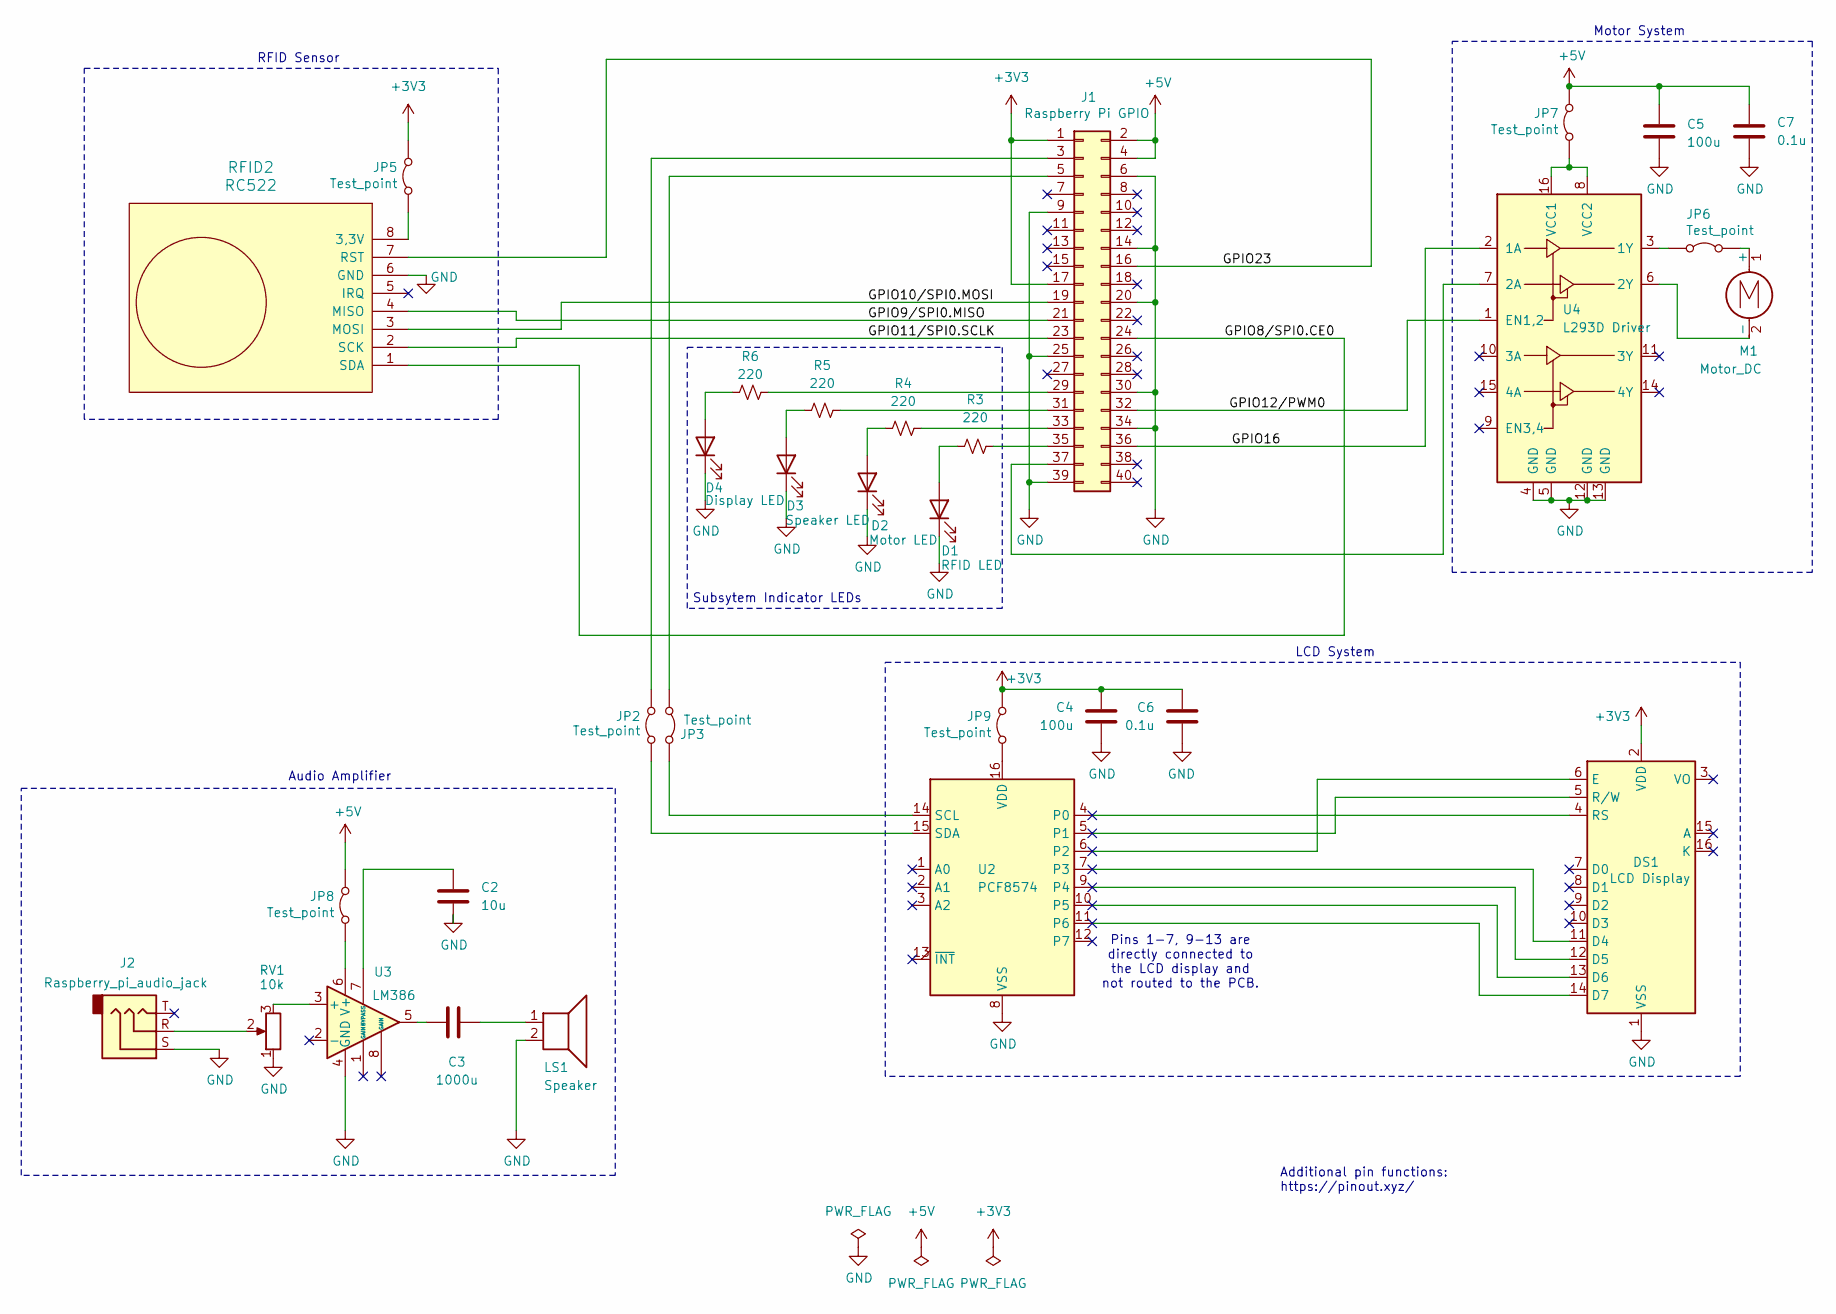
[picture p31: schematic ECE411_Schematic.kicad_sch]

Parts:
C2: 10u; C_Radial_D5.0mm_H11.0mm_P2.00mm
C3: 1000u; C_Radial_D10.0mm_H20.0mm_P5.00mm
C4, C5: 100u; C_0805_2012Metric_Pad1.18x1.45mm_HandSolder
C6, C7: 0.1u; C_0805_2012Metric_Pad1.18x1.45mm_HandSolder
D1: RFID LED; LED_Yuji_5730
D2: Motor LED; LED_Yuji_5730
D3: Speaker LED; LED_Yuji_5730
D4: Display LED; LED_Yuji_5730
DS1: LCD Display
J1: Raspberry Pi GPIO; PinSocket_2x20_P2.54mm_Vertical
J2: Raspberry_pi_audio_jack
JP2, JP3, JP5, JP6, JP7, JP8, JP9: Test_point; R_Axial_DIN0204_L3.6mm_D1.6mm_P2.54mm_Vertical
LS1: Speaker
M1: Motor_DC; Motor
R3, R4, R5, R6: 220; R_0805_2012Metric_Pad1.20x1.40mm_HandSolder
RFID2: RC522
RV1: 10k; Potentiometer_Bourns_3299W_Vertical
U2: PCF8574; LCD1602
U3: LM386; DIP-8_W7.62mm
U4: L293D Driver; DIP-16_W7.62mm

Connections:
+3V3: C4.1, C6.1, DS1.2 (VDD), J1.1, J1.17, JP5.2 (B), JP9.2 (B)
+5V: C5.1, C7.1, J1.2, J1.4, JP7.2 (B), JP8.2 (B)
/GPIO8/SPI0.CE0: J1.24, RFID2.1 (SDA); also elsewhere on the board
/GPIO9/SPI0.MISO: J1.21, RFID2.4 (MISO); also elsewhere on the board
/GPIO10/SPI0.MOSI: J1.19, RFID2.3 (MOSI); also elsewhere on the board
/GPIO11/SPI0.SCLK: J1.23, RFID2.2 (SCK); also elsewhere on the board
/GPIO12/PWM0: J1.32, U4.1 (EN1,2)
/GPIO16: J1.36, U4.2 (1A)
/GPIO23: J1.16, RFID2.7 (RST); also elsewhere on the board
GND: C2.2, C4.2, C5.2, C6.2, C7.2, D1.1 (K), D2.1 (K), D3.1 (K), D4.1 (K), DS1.1 (VSS), J1.6, J1.9, J1.14, J1.20, J1.25, J1.30, J1.34, J1.39, J2.S, LS1.2, RFID2.6 (GND), RV1.1, U2.8 (VSS), U3.4 (GND), U4.4 (GND), U4.5 (GND), U4.12 (GND), U4.13 (GND); also elsewhere on the board
unnamed: C3.1, U3.5
unnamed: C3.2, LS1.1
unnamed: D1.2 (A), R3.1
unnamed: D2.2 (A), R4.1
unnamed: D3.2 (A), R5.1
unnamed: D4.2 (A), R6.1
unnamed: DS1.4 (RS), U2.4 (P0)
unnamed: DS1.5 (R/W), U2.5 (P1)
unnamed: DS1.6 (E), U2.6 (P2)
unnamed: DS1.11 (D4), U2.7 (P3)
unnamed: DS1.12 (D5), U2.9 (P4)
unnamed: DS1.13 (D6), U2.10 (P5)
unnamed: DS1.14 (D7), U2.11 (P6)
unnamed: J1.3, JP2.2 (B)
unnamed: J1.5, JP3.1 (A)
unnamed: J1.29, R6.2
unnamed: J1.31, R5.2
unnamed: J1.33, R4.2
unnamed: J1.35, R3.2
unnamed: J1.37, U4.7 (2A)
unnamed: JP2.1 (A), U2.15 (SDA)
unnamed: JP3.2 (B), U2.14 (SCL)
unnamed 32: JP5.1 (A), RFID2.8 (3,3V); also elsewhere on the board
unnamed: JP6.1 (A), U4.3 (1Y)
unnamed: JP6.2 (B), M1.1 (+)
unnamed: JP7.1 (A), U4.8 (VCC2), U4.16 (VCC1)
unnamed: JP8.1 (A), U3.6 (V+)
unnamed: JP9.1 (A), U2.16 (VDD)
unnamed: M1.2 (-), U4.6 (2Y)
unnamed: J2.R, RV1.2
unnamed: RV1.3, U3.3 (+)
unnamed: C2.1, U3.7 (BYPASS)

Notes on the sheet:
RFID Sensor
LCD System
Additional pin functions: https://pinout.xyz/
Audio Amplifier
Motor System
Pins 1-7, 9-13 are directly connected to the LCD display and not routed to the PCB.
Subsytem Indicator LEDs

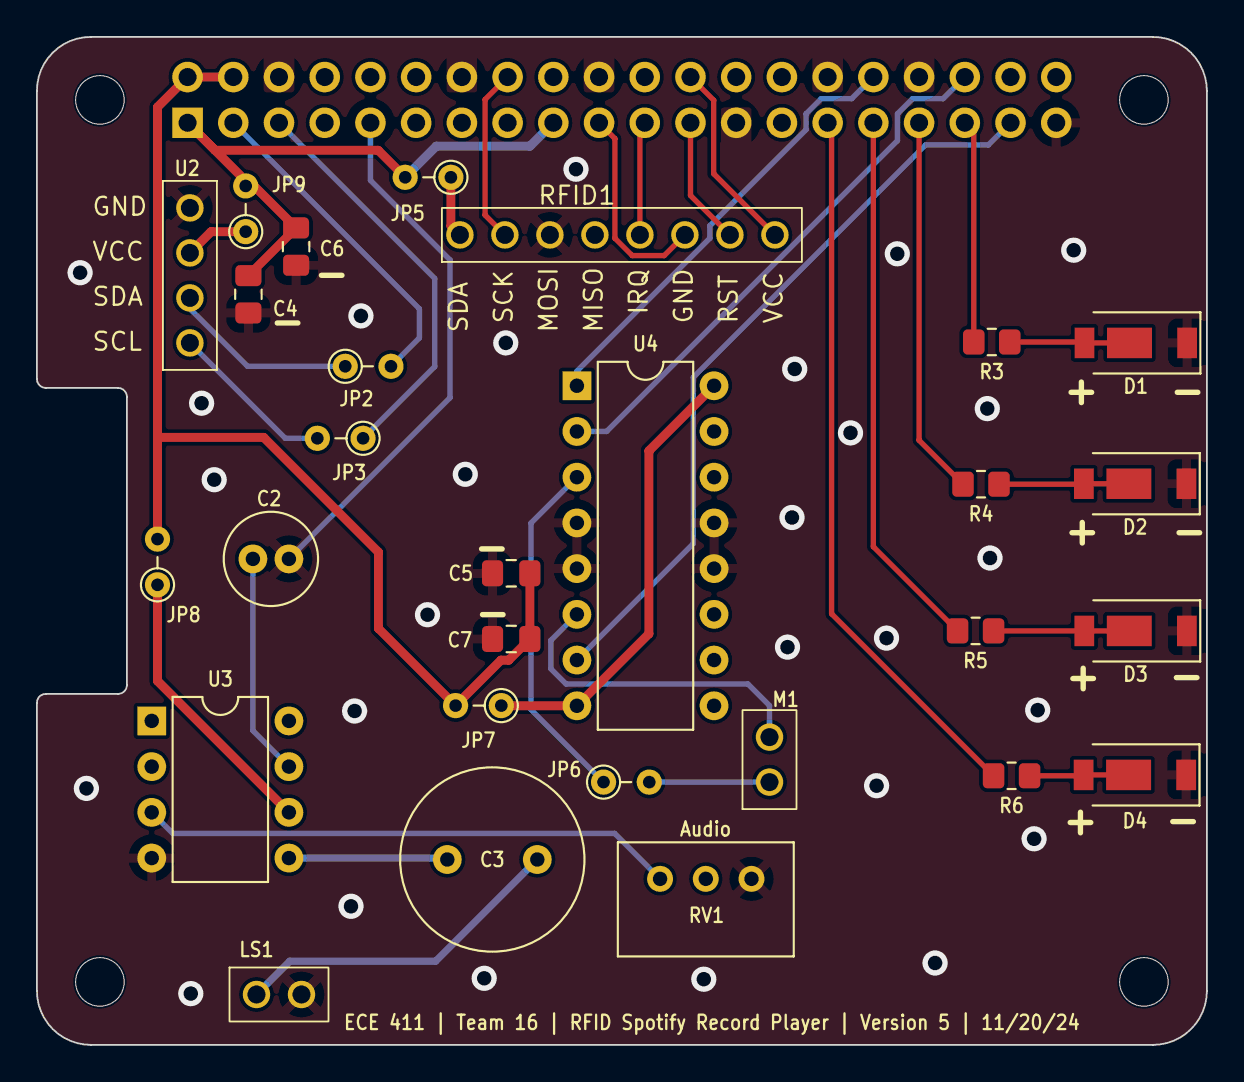
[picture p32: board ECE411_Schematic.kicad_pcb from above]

Board: 2 copper layers, 65.0 x 56.0 mm, 33 parts (1 on the bottom side), 34 nets.

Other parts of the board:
MH1, MH2, MH3, MH4: MountingHole_2.7mm_M2.5
RFID1: RC522

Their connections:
/GPIO8/SPI0.CE0: RFID1.1 (SDA); also elsewhere on the board
/GPIO9/SPI0.MISO: RFID1.4 (MISO); also elsewhere on the board
/GPIO10/SPI0.MOSI: RFID1.3 (MOSI); also elsewhere on the board
/GPIO11/SPI0.SCLK: RFID1.2 (SCK); also elsewhere on the board
/GPIO23: RFID1.7 (RST); also elsewhere on the board
GND: RFID1.6 (GND); also elsewhere on the board
unnamed 32: RFID1.8 (3,3V); also elsewhere on the board

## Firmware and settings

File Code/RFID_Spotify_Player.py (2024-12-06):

import threading
from mfrc522 import SimpleMFRC522
import RPi.GPIO as GPIO
import spotipy
from spotipy.oauth2 import SpotifyOAuth
from time import sleep
import sqlite3
from RPLCD.i2c import CharLCD
import queue

# Setup constants
DEVICE_ID = "98bb0735e28656bac098d927d410c3138a4b5bca"#ab8d7970b75"
CLIENT_ID = "fc465222f6a94ee292f29574f20398e9"
CLIENT_SECRET = "b5e442bdbaee418da3c4bab8d7970b75"

# GPIO Pins
MOTOR_DIRECTION_PIN = 16
MOTOR_INVERTED_PIN = 26
PWM_PIN = 12
REGISTER_RFID_TAG = 839325964744
PAUSE_PLAYBACK = 114259767899
PLAY_PLAYBACK = 115686027819
SKIP_PLAYBACK = 389775340099
LCD_LED_PIN = 5
SPEAKER_LED_PIN = 6
MOTOR_LED_PIN = 13
RFID_LED_PIN = 19

# GPIO Setup
GPIO.setmode(GPIO.BCM)

GPIO.setup(SPEAKER_LED_PIN, GPIO.OUT)
GPIO.setup(LCD_LED_PIN, GPIO.OUT)
GPIO.setup(MOTOR_LED_PIN, GPIO.OUT)
GPIO.setup(RFID_LED_PIN, GPIO.OUT)

GPIO.output(LCD_LED_PIN, GPIO.LOW)
GPIO.output(SPEAKER_LED_PIN, GPIO.LOW)
GPIO.output(RFID_LED_PIN, GPIO.LOW)
GPIO.output(MOTOR_LED_PIN, GPIO.LOW)

GPIO.setup(MOTOR_DIRECTION_PIN, GPIO.OUT)
GPIO.setup(MOTOR_INVERTED_PIN, GPIO.OUT)
GPIO.setup(PWM_PIN, GPIO.OUT)

pwm = GPIO.PWM(PWM_PIN, 1000)  # Motor PWM
pwm.start(0)

# Spotify Initialization
sp = spotipy.Spotify(auth_manager=SpotifyOAuth(
    client_id=CLIENT_ID,
    client_secret=CLIENT_SECRET,
    redirect_uri="http://localhost:8080",
    scope="user-read-playback-state,user-modify-playback-state"
))

# LCD Initialization
lcd = CharLCD('PCF8574', 0x27)  # Update I2C address if necessary

# SQLite Database
conn = sqlite3.connect('rfid_spotify.db', check_same_thread=False)
c = conn.cursor()
c.execute('''
          CREATE TABLE IF NOT EXISTS tag_to_uri (
              tag_id INTEGER PRIMARY KEY,
              uri TEXT,
              start_track_uri TEXT,
              track_position INTEGER
          )
          ''')
conn.commit()
#c.execute("ALTER TABLE tag_to_uri ADD COLUMN track_position INTEGER")
# Global Variables
stop_threads = False
lcd_message_queue = queue.Queue()  # LCD message queue


# LED Control Functions
def set_lcd_led(state):
    GPIO.output(LCD_LED_PIN, GPIO.HIGH if state else GPIO.LOW)


def set_motor_led(state):
    GPIO.output(MOTOR_LED_PIN, GPIO.HIGH if state else GPIO.LOW)


def set_speaker_led(state):
    GPIO.output(SPEAKER_LED_PIN, GPIO.HIGH if state else GPIO.LOW)


def set_rfid_led(state):
    GPIO.output(RFID_LED_PIN, GPIO.HIGH if state else GPIO.LOW)


# Motor Control
def set_motor(speed, direction):
    if speed > 0:
        set_motor_led(True)
    else:
        set_motor_led(False)
    pwm.ChangeDutyCycle(speed)
    GPIO.output(MOTOR_DIRECTION_PIN, direction)
    GPIO.output(MOTOR_INVERTED_PIN, not direction)


# LCD Message Queue
def display_message(line1, line2, duration=2):
    lcd_message_queue.put((line1, line2, duration))


def process_lcd_messages():
    """Process LCD messages, falling back to current song display."""
    current_uri = None
    while not stop_threads:
        try:
            if not lcd_message_queue.empty():
                line1, line2, duration = lcd_message_queue.get()
                lcd.clear()
                lcd.cursor_pos = (0, 0)
                lcd.write_string(line1[:16])
                lcd.cursor_pos = (1, 0)
                lcd.write_string(line2[:16])
                set_lcd_led(True)
                sleep(duration)
                set_lcd_led(False)
            else:
                playback = sp.current_playback()
                if playback and playback.get('item'):
                    track = playback['item']
                    uri = track['uri']
                    if uri != current_uri:
                        current_uri = uri
                        song_name = track['name']
                        artist_name = ", ".join(artist['name'] for artist in track['artists'])
                        lcd.clear()
                        lcd.cursor_pos = (0, 0)
                        lcd.write_string(song_name[:16])
                        lcd.cursor_pos = (1, 0)
                        lcd.write_string(artist_name[:16])
                sleep(5)
        except Exception as e:
            print(f"Error processing LCD messages: {e}")
            sleep(5)


# Spotify Track Info
def get_track_name():
    try:
        track_info = sp.current_playback()
        if track_info:
            return track_info['item']['name']
    except Exception as e:
        print(f"Error retrieving track info: {e}")
    return "Unknown Track"


# Playback Status
def check_playback_status():
    """Monitor Spotify playback and control motor."""
    global stop_threads
    while not stop_threads:
        try:
            playback = sp.current_playback()
            if playback and playback.get('is_playing', False):
                set_motor(34, True)
                set_speaker_led(True)
            else:
                set_motor(0, False)
                set_speaker_led(False)
        except Exception as e:
            print(f"Error checking playback status: {e}")
        sleep(1)


# Register RFID Tags
def register_tag(tag_id, uri, start_track_uri, track_position):
    try:
        c.execute("INSERT OR REPLACE INTO tag_to_uri (tag_id, uri, start_track_uri, track_position) VALUES (?, ?, ?, ?)", (tag_id, uri, start_track_uri, track_position))
        conn.commit()
        display_message("Tag Registered", "Successfully!", 5)
    except Exception as e:
        print(f"Error registering tag: {e}")
        display_message("Registration Failed", "Try Again", 5)


# RFID Playback
def play_song_from_rfid():
    global stop_threads
    reader = SimpleMFRC522()
    try:
        while not stop_threads:
            set_rfid_led(True)
            id, _ = reader.read()
            print(id)
            if id == PAUSE_PLAYBACK:
                sp.pause_playback(device_id=DEVICE_ID)
                set_motor(0, False)
                display_message("Playback", "Paused", 2)
                continue
            if id == PLAY_PLAYBACK:
                sp.start_playback(device_id=DEVICE_ID)
                display_message("Playback", "Resumed", 2)
                continue
            if id == SKIP_PLAYBACK:
                sp.next_track(device_id=DEVICE_ID)
                sp.start_playback(device_id=DEVICE_ID)
                display_message("Skipping", "Next Track", 2)
                continue

            if id == REGISTER_RFID_TAG:
                display_message("Registration", "Mode Active", 2)
                while True:
                    id, _ = reader.read()
                    if (id != PAUSE_PLAYBACK and id != PLAY_PLAYBACK and id != SKIP_PLAYBACK):
                        continue
                    if id != REGISTER_RFID_TAG:
                        uri = sp.current_playback()
                        if uri and uri.get('item'):
                            album_uri = uri['item']['album']['uri']
                            track_uri = uri['item']['uri']
                            album_tracks = sp.album_tracks(album_uri)['items']
                            track_position = next((i for i, t in enumerate(album_tracks) if t['uri'] == track_uri), 0
                            )
                            track_name = uri['item']['name']
                            
                            register_tag(id, album_uri, track_uri,track_position)
                        else:
                            display_message("No Playback Found", "Start Spotify", 2)
                        break
                continue

            c.execute("SELECT uri, start_track_uri, track_position FROM tag_to_uri WHERE tag_id=?", (id,))
            result = c.fetchone()
            print(f"datab result for tag {id}: {result}")
            for row in c.execute("SELECT * FROM tag_to_uri"):
                print(row)
            if result:
                album_uri, start_track_uri, track_position = result
                
                #uri = result[0]
                sp.start_playback(device_id=DEVICE_ID, context_uri=album_uri, offset={"position": track_position})
                
                #sleep(1)
                #sp.start_playback(device_id=DEVICE_ID, uris=[start_track_uri])
                track_name = sp.track(start_track_uri)['name']#get_track_name()
                display_message("Playing", track_name[:16], 2)
            else:
                display_message("Tag Not Found", "Please Register", 2)
            sleep(1)
    finally:
        set_rfid_led(False)


# Main Program
def main():
    global stop_threads
    try:
        playback_thread = threading.Thread(target=check_playback_status, daemon=True)
        rfid_thread = threading.Thread(target=play_song_from_rfid, daemon=True)
        lcd_thread = threading.Thread(target=process_lcd_messages, daemon=True)

        playback_thread.start()
        rfid_thread.start()
        lcd_thread.start()

        while True:
            sleep(1)
    except KeyboardInterrupt:
        stop_threads = True
        playback_thread.join()
        rfid_thread.join()
        lcd_thread.join()
    finally:
        lcd.clear()
        GPIO.cleanup()
        conn.close()


if __name__ == "__main__":
    main()

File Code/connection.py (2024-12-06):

import spotipy
from spotipy.oauth2 import SpotifyOAuth
from time import sleep

# Spotify Credentials
CLIENT_ID = "fc465222f6a94ee292f29574f20398e9"
CLIENT_SECRET = "b5e442bdbaee418da3c4bab8d7970b75"

# Spotify Initialization
sp = spotipy.Spotify(auth_manager=SpotifyOAuth(
    client_id=CLIENT_ID,
    client_secret=CLIENT_SECRET,
    redirect_uri="http://localhost:8080",
    scope="user-read-playback-state,user-modify-playback-state"
))

def check_raspotify_connection(device_name="raspotify"):
    """Check if the specified Spotify device is connected."""
    while True:
        try:
            devices = sp.devices()
            for device in devices.get('devices', []):
                if device['name'].lower() == device_name.lower():
                    print(f"{device_name} is connected.")
                    return device['id']  # Return the device ID
            print(f"Waiting for {device_name} to connect...")
        except Exception as e:
            print(f"Error checking devices: {e}")
        sleep(5)  # Retry every 5 seconds

if __name__ == "__main__":
    print("Checking Raspotify connection...")
    DEVICE_ID = check_raspotify_connection("raspotify")  # Replace "raspotify" with your device name
    print(f"Raspotify connected! Device ID: {DEVICE_ID}")

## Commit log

2024-11-02 Add files via upload
    Added major components with the appropriate connections to the Raspberry Pi. Still need to adjust the layout and see how it looks in PCB view.
2024-11-06 Add files via upload
    Code for Raspberry Pi
2024-11-07 Updated schematic
    Added in parts that was tested and worked on the device we are currently building.
2024-11-07 Preliminary layout of the PCB
2024-11-07 Current progress on the project with video demo
2024-11-14 Rename ECE411_Preliminary_Schematic.pdf to Schematic and Layout/ECE411_Preliminary_Schematic.pdf
2024-11-14 Add files via upload
    Third version of the schematic. Added no connect instead of remove the pins entirely. Also added the LCD circuit.
2024-11-14 Rename ECE411_Layout.pdf to Schematic and Layout/ECE411_Layout.pdf
2024-11-14 Add files via upload
    Second version of the schematic layout. Added the LCD screen connection and finished all the connections for all other components.
2024-11-17 KiCad Project Files
    [ECE411_Schematic.kicad_pcb, ECE411_Schematic.kicad_sch]
2024-11-17 added LEDs to indicate functioning subsystems
    [ECE411_Schematic.kicad_pcb, ECE411_Schematic.kicad_sch]
2024-11-19 Added test points, and subsystem led indicators
2024-11-19 Add files via upload
    Case for RPi, RFID, motor, amp PCB - Rev 1
    [3d_Bottom_rev1.stl, 3d_Top_rev1.stl]
2024-11-19 Added SMD components to the PCB and rerouted a few traces
2024-11-19 Version 5 schematic and layout
    [ECE411_Schematic.kicad_pcb]
2024-11-20 Version 6 schematic and Version 4 Layout
    [ECE411_Schematic.kicad_pcb, ECE411_Schematic.kicad_sch]
2024-11-20 Version 6 Schematic
2024-11-21 Final layout and schematic
    [ECE411_Schematic.kicad_pcb, ECE411_Schematic.kicad_sch]
2024-11-22 added a database to store the RFID IDs, motor, and speaker for audio output
2024-12-06 Create LEDs
